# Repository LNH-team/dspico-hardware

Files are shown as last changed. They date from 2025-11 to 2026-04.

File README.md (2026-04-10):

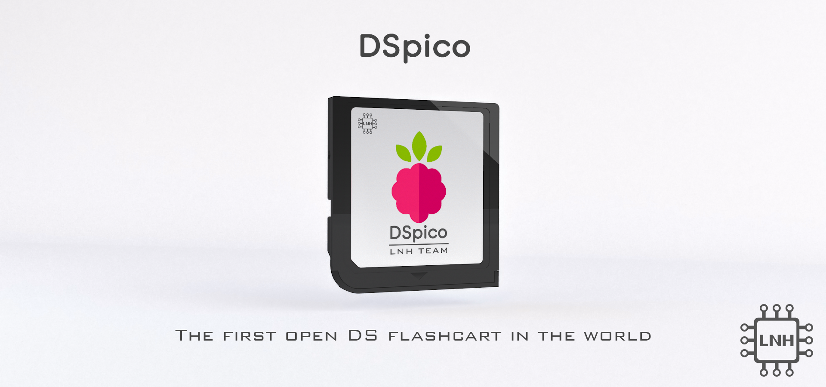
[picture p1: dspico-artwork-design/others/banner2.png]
DSpico-banner


# DSpico Hardware
## 🗺️ Contents
- [ℹ Introduction](#ℹ-introduction)
- [❔ About this repository](#-about-this-repository).
- [🎮 DSpico PCB](#-dspico-pcb)
- [🧰 DSpico Shell](#-dspico-shell)
- [🎨 Artwork: Stickers and box art](#-artwork-stickers-and-box-art)
- [📦 Instructions](#-instructions)
- [🛠 Development](#-development)
- [👥 Contributions](#-contributions)
- [👾 Discord](#-discord)
- [📋 LNH Team Statement](#-lnh-team-statement)
- [⚖ License](#-license)

## ℹ Introduction
### What is DSpico?
DSpico is the world's first open-source DS(i) flashcart, created by the LNH team. Everything from the PCB, shell, stickers, and box art is open-source. You can either build it yourself as a DIY project or have it made by a manufacturer.

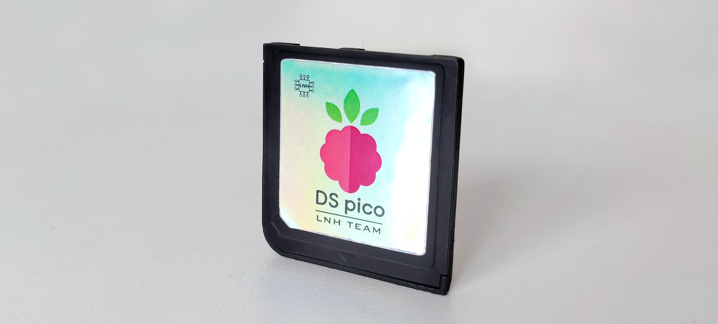
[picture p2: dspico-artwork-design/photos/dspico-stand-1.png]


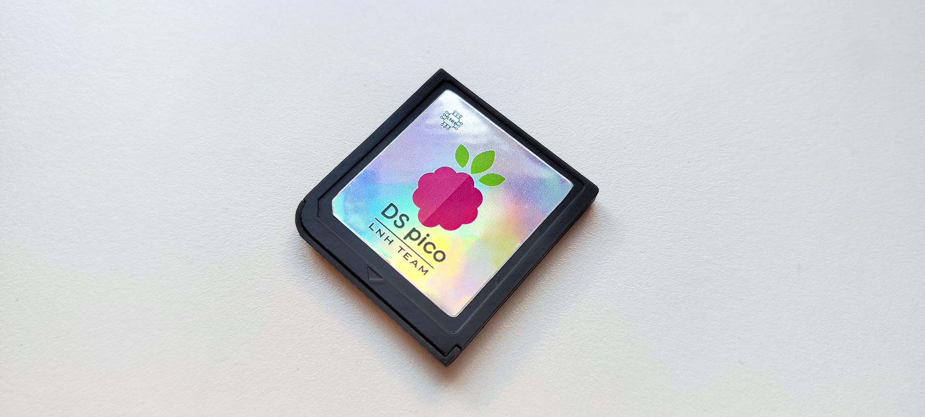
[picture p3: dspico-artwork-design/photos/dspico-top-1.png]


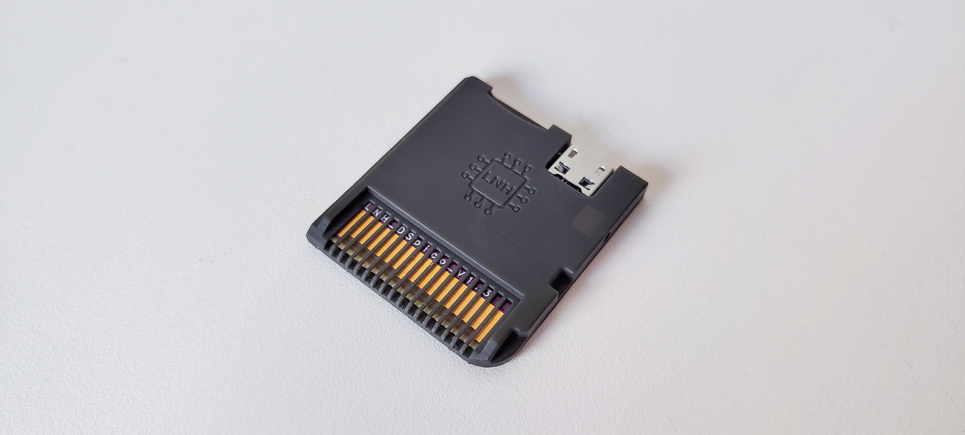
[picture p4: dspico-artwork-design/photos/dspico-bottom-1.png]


### Features
- RP2040 microcontroller
- 16 Mbit flash memory
- Micro USB port
- Micro SD slot
- Development port
- Two LEDs (red and blue)
- Dual power support: can be powered by USB and DS simultaneously (by ORing circuit)

With the [DSpico Firmware](https://github.com/LNH-team/dspico-firmware):
- Sequential SD read speed: up to 6MB/s
- Power consuption: ~57 mW
- Compatible with DSi mode
- Compatible with [Pico Loader](https://github.com/LNH-team/pico-loader) and [Pico Launcher](https://github.com/LNH-team/pico-launcher)

## ❔ About this repository
This repository contains the necessary files for the hardware of the DSpico, including a PCB, CAD design of the shell, stickers for cartridge and box art.

## 🎮 DSpico PCB
The PCB design is located in the [`dspico-pcb`](dspico-pcb) folder. This folder contains all the necessary files for PCB fabrication, as well as the design files created using the electronic design software.

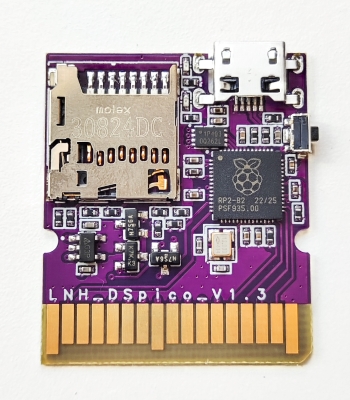
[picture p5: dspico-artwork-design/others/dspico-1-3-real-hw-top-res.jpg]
DSpico-top

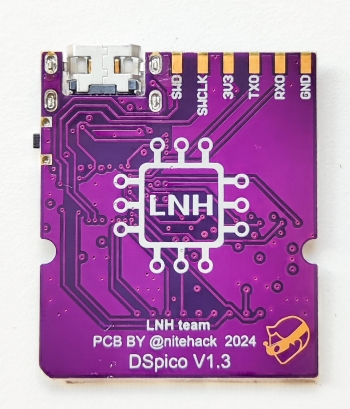
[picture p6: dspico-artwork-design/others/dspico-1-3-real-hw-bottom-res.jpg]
DSpico-bottom

### 📂 Included Subfolders:
- [`design-files`](dspico-pcb/design-files): PCB schematic and layout of DSpico. (KiCad format)
- [`fabrication-files`](dspico-pcb/fabrication-files): Gerber files, Pick&Place files and BOM for PCB fabrication of DSpico.
- [`docs`](dspico-pcb/docs): Documentation for manufacturing and assembling DSpico.

### 🔌 Pinout

| **Peripheral**  | **Pin name - Peripheral** | **Pin name - RP2040** | **Pin number - RP2040** |
|---|---|---|---|
| **DS Slot** | D0 | GPIO12 | 15 |
| | D1 | GPIO13 | 16 |
| | D2 | GPIO14 | 17 |
| | D3 | GPIO15 | 18 |
| | D4 | GPIO16 | 27 |
| | D5 | GPIO17 | 28 |
| | D6 | GPIO18 | 29 |
| | D7 | GPIO19 | 30 |
| | CLK_DS | GPIO11 | 14 |
| | ROM_CS | GPIO10 | 13 |
| | SPI_CS | GPIO21 | 32 |
| | IRQ | GPIO20 | 31 |
| | RST_DS | GPIO09 | 12 |
| **SD slot**| CLK_SD | GPIO03 | 5 |
| | DAT0 | GPIO05 | 7 |
| | DAT1 | GPIO06 | 8 |
| | DAT2 | GPIO07 | 9 |
| | DAT3 | GPIO08 | 11 |
| | CMD | GPIO04 | 6 |
| **DEV port**| SWD | SWD | 25 |
| | SWCLK | SWCLK | 24 |
| | TX | GPIO0 | 2 |
| | RX | GPIO1 | 3 |
| **Blue LED** | LED_B | GPIO28 | 40 |
| **Red LED** | LED_R | GPIO27 | 39 |

## 🧰 DSpico Shell

The CAD design of the shell is located in the [`dspico-shell`](dspico-shell) folder. This folder contains 3D models of the shell (output 3d models and design files), which can be viewed and modified using CAD design software Autodesk Inventor

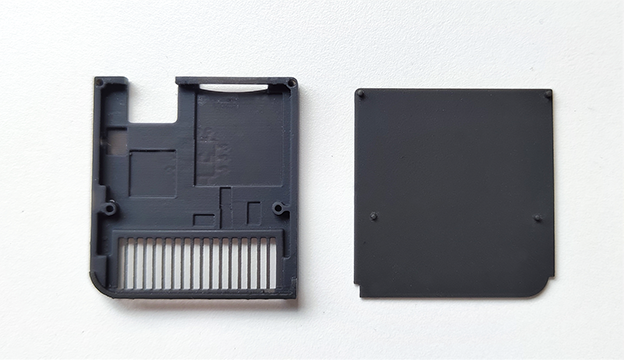
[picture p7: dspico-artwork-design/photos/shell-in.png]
DSpico-shell-in

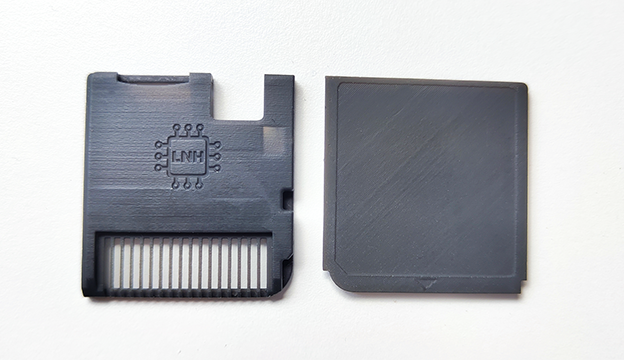
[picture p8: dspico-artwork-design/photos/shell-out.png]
DSpico-shell-out

### 📂 Included Subfolders:
- [`design-files`](dspico-shell/design-files): Contains source design files for the shell
- [`3d-models`](dspico-shell/3d-models): Contains 3D models of the shell in STL and STEP format for fabrication.

## 🎨 Artwork: Stickers and box art
The stickers and box art design are located in the [`dspico-artwork-design`](dspico-artwork-design).  This folder contains stickers for cartridge and box art in SVG, PSD and PNG formats.

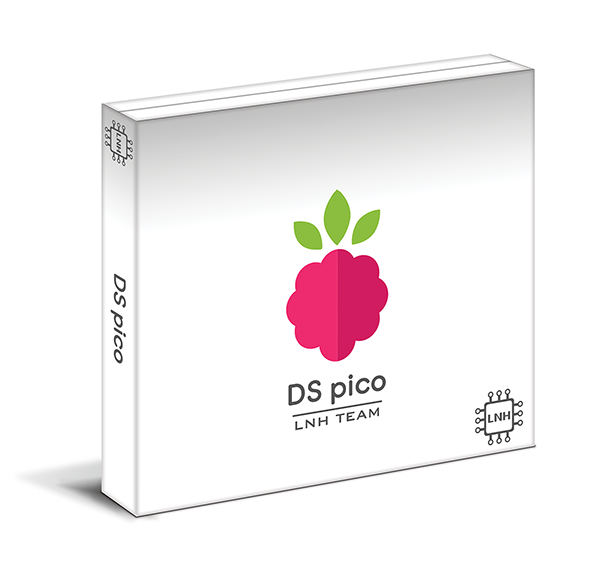
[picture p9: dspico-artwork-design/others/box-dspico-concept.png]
DSpico-box

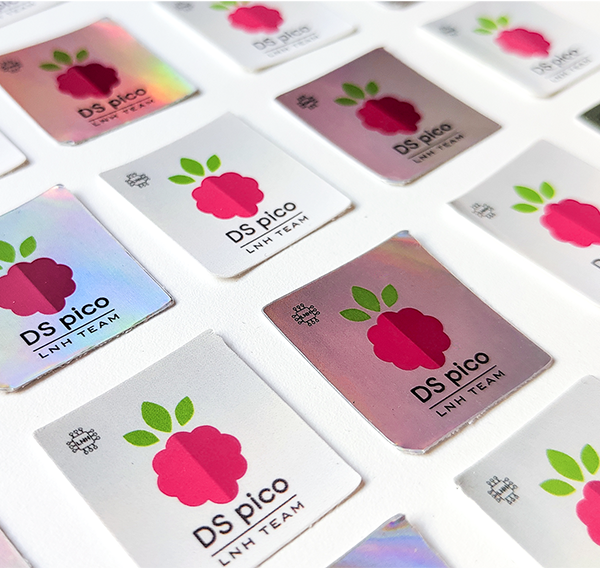
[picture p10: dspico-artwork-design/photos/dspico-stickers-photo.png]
DSpico-stickers


### 📂 Included Subfolders:
- [`stickers`](dspico-artwork-design/stickers): Stickers to print and put on your DSpico cartridge.
- [`box-art`](dspico-artwork-design/box-art): Box art design to print and put on your DS box.
- [`logo`](dspico-artwork-design/logo): DSpico logo in different formats.
- [`others`](dspico-artwork-design/others): Other graphics related to DSpico

## 📦 Instructions
### 1️⃣ Build
1. **Manufacture the PCB and Shell**<br>
    Start by producing both the PCB and the shell. Go to the respective sections, [`dspico-pcb`](dspico-pcb) and [`dspico-shell`](dspico-shell), and read the README file in each to understand how to create these parts.

2. **Optional: Customize with a Sticker and Box Art**<br>
    If desired, you can print a sticker from the stickers section and add box art [`dspico-artwork-design`](dspico-artwork-design) for storing your DSpico (for example, by reusing an existing box).

### 2️⃣ Assembly
Once you have both the PCB and the shell manufactured, the next step is to assemble them. Follow these steps:
1. First, insert the PCB into the bottom part of the shell.
2. Next, attach the top part of the shell by aligning the pegs with the holes in the bottom part.
3. Stick your favorite DSpico sticker on top part.
Make sure everything fits, and your DSpico will be ready for the next steps!

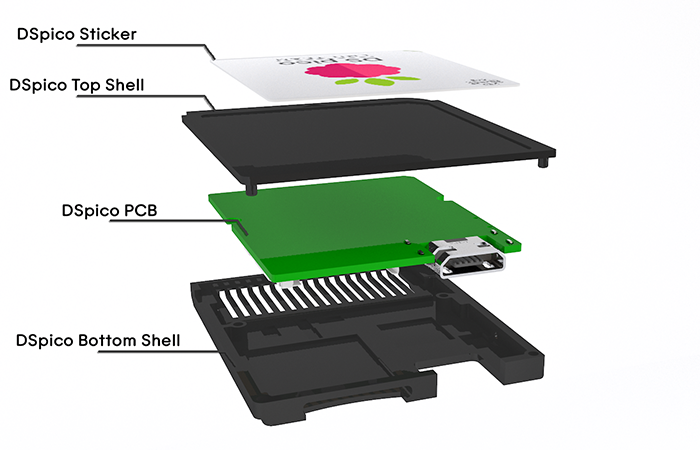
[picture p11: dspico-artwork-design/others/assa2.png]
DSpico-assembly2

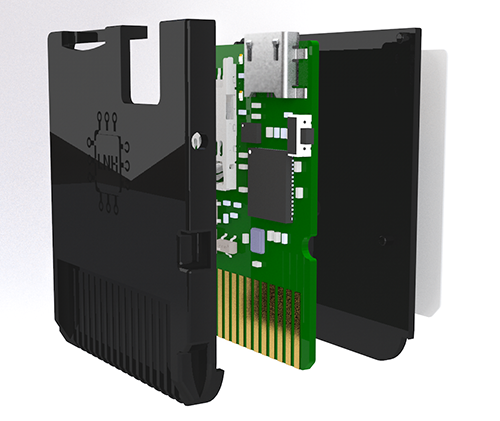
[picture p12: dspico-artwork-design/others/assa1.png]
DSpico-assembly1


### 3️⃣ Setup the software
Follow the [guide](https://github.com/LNH-team/dspico/blob/develop/GUIDE.md) for instructions on how to compile and setup the firmware and the contents of the micro SD card.

## 🛠 Development
The DSpico features a development port for creating new applications and developing new peripherals. The available communication ports are as follows:
- UART
- I2C
- x2 GPIO
- SWD (debug)

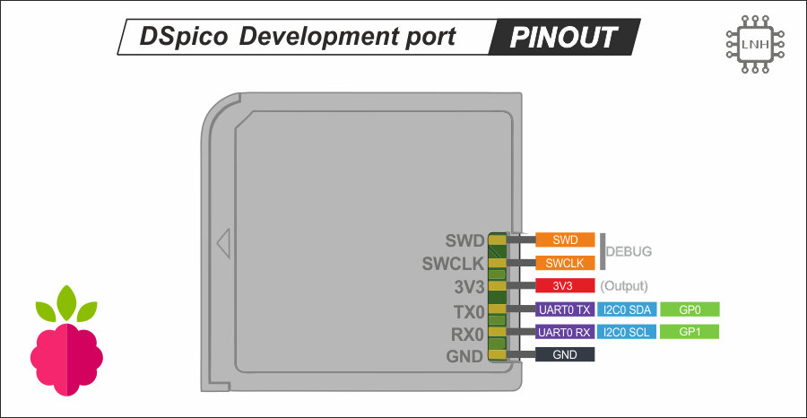
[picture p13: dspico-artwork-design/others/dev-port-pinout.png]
development port


As for the power it can provide to peripherals, it is:
- 3.3 V (up to 50 mA)

The pitch between pins of this port is 2.54 mm such that some connectors can be soldered (as long as it does not interfere with the rest of the DSpico mechanics). For example a male or female header.

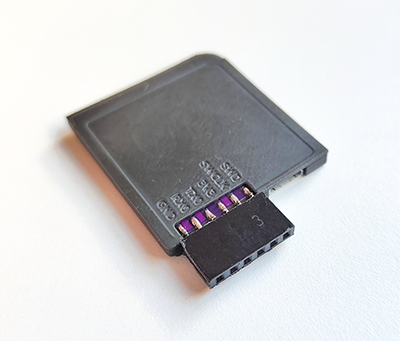
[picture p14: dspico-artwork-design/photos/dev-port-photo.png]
DSpico-dev-port

## 👥 Contributions

Contributions are welcome. If you wish to improve the PCB or shell designs, feel free to submit a pull request!

### Contributors:

#### PCB:
 - [nitehack](https://www.github.com/nitehack)
 - [Gericom](https://github.com/Gericom) (first DSpico prototype)

#### Shell:
 - rcuevas
 - [nitehack](https://www.github.com/nitehack)

#### Artworks:
 - [nitehack](https://www.github.com/nitehack)

## 👾 Discord
- [DS⁽ⁱ⁾ Mode Hacking!](https://discord.gg/fCzqcWteC4)

## 📋 LNH Team Statement
We wish to make it clear that the LNH team has no affiliation with any commercial projects, and we do not endorse or engage in any for-profit endeavors concerning DSpico or related materials. This statement serves as a formal disavowal of any financial or business dealings that may arise in relation to DSpico, and we take no responsibility for any actions or transactions carried out by third parties in this regard.

## ⚖ License

This project is licensed under the CC BY-SA 4.0 License. See the [`LICENSE`](LICENSE) file for more details.

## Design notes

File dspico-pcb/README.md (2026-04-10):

# DSpico PCB

This repository contains the files and configurations needed to fabricate and assemble the PCB for the **DSpico** flashcart. You can manufacture with the manufacturer you prefer. In this readme we include a guide on how to order it from [JLCPCB](https://cart.jlcpcb.com/quote?spm=Jlcpcb.Homepage.1006)

## 📂 Included Subfolders:
- [`design-files`](./design-files): PCB schematic and layout of DSpico. (KiCad format)
- [`fabrication-files`](./fabrication-files): Gerber files, Pick&Place files and BOM for PCB fabrication of DSpico.
   - 📂 `Gerber`: Gerber files required for fabrication.
   - 📂 `NC Drill`: Contains the NC Drill files required for PCB hole drilling.
   - 📂 `BOM`: Bill of Materials (BOM) for assembly.
   - 📂 `Pick Place`: Pick and Place files for component placement.
- [`docs`](./docs): Documentation for manufacturing and assembling DSpico. (including schematics)

---

## 📦 Guide to get a PCB
DSpico-top
DSpico-bottom

### 1. PCB Order- JLCPCB
> [!WARNING]
> This guide was last reviewed on **November 22, 2025**. 
> Please be aware that the manufacturer's website and production processes may have changed since this date. 

1. **Prepare files**
   - Make a compressed file ZIP of `NC Drill` and `Gerber` folder with the name of `Gerber.zip` (for example)
2. **Go to the Website of manufacturer**
  
   - Visit [JLCPCB PCB Quote](https://cart.jlcpcb.com/quote).

3. **Upload Gerber and NC Drill Files**:

   - Upload the `Gerber.zip` file to the JLCPCB configurator.

4. **PCB Configuration**

   - Base Material: **FR-4**
   - Number of Layers: **4 layers** (auto-detected after uploading Gerber files).
   - Dimensions: (auto-detected after uploading Gerber files).
   - Quantity: **5 units** (minimum)

>PCB Specifications
   - Deburring/Edge rounding: Yes
   - Different Design: 1
   - Delivery Format : Single PCB
   - PCB Thickness: **0.8mm** (very important)
   - PCB Color: (As you want but normally green is the cheapest)
   - Silkscreen: **White** 
   - Material Type: FR4 TG135
   - Surface Finish: **ENIG**
   - Gold Thickness: **1U"**. (Or more, but more expensive)
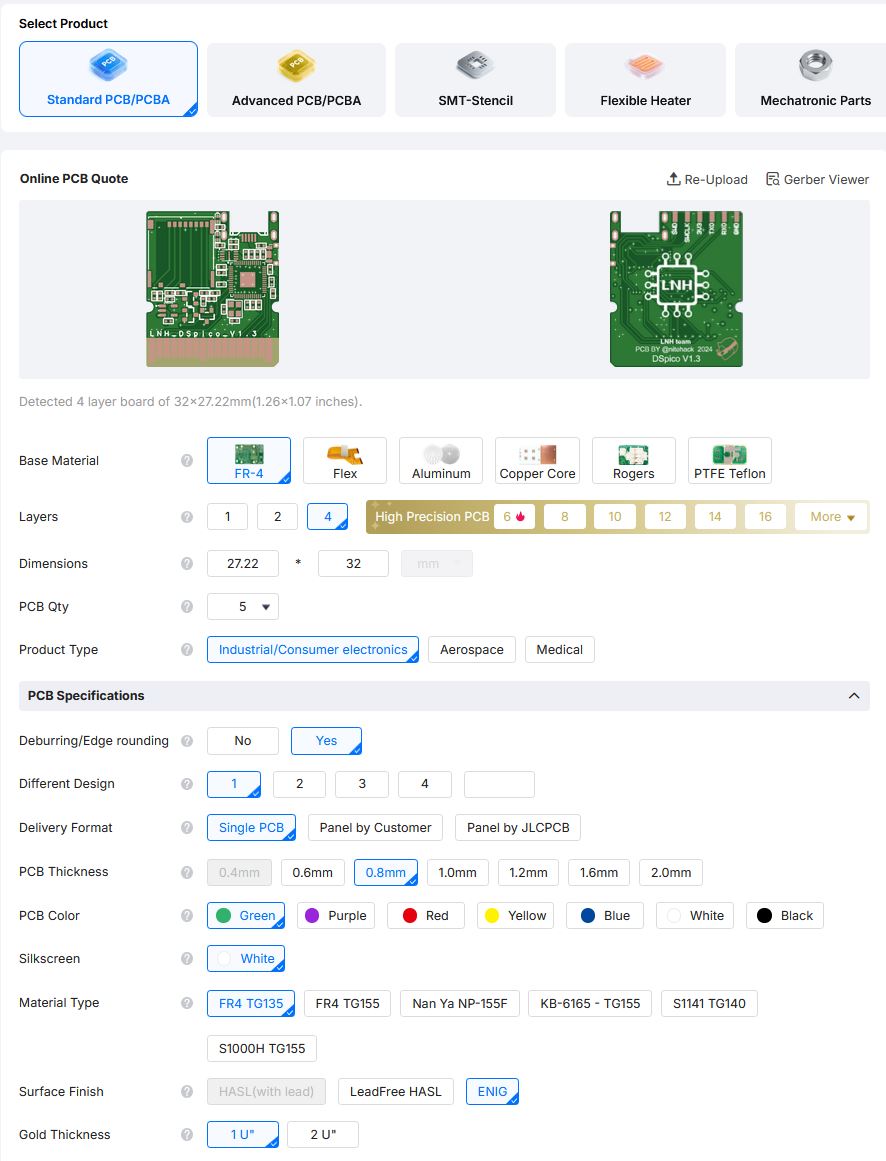
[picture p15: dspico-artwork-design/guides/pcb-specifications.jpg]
pcb-specifications


>High-spec Options
   - Outer Copper Weight: **1 oz**
   - Inner Copper weight: **0.5 oz**
   - Specify Layer Sequence: YES
      
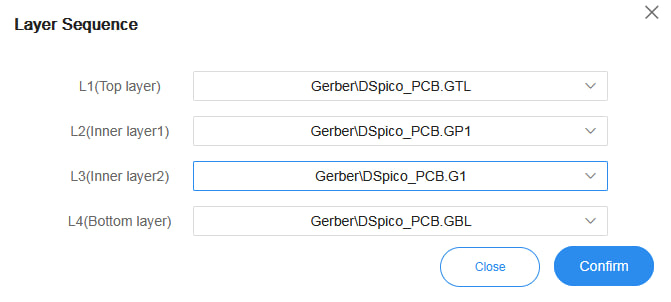
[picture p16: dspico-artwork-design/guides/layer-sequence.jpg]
layer-sequence


   - Specify Stackup: **No**
   - Via Covering: **Plugged**
   - Min via hole size/diameter: **0.3mm (0.4/0.45mm)**
   - Board Outline Tolerance: **±0.2mm (Regular)**
   - Confirm Production File: **Yes**
   - Mark on PCB: **Remove Mark**
   - Electrical Test: **Flying Probe Fully Test**
   - Gold Fingers: **No**
   - Castellated Holes: **No**
   - Press-Fit Holes: **No**
   - Edge Plating: **No**
   - Blind Slots: **No**
   - UL Marking: **No**
   - Via Plating Method: **Not Specified** 
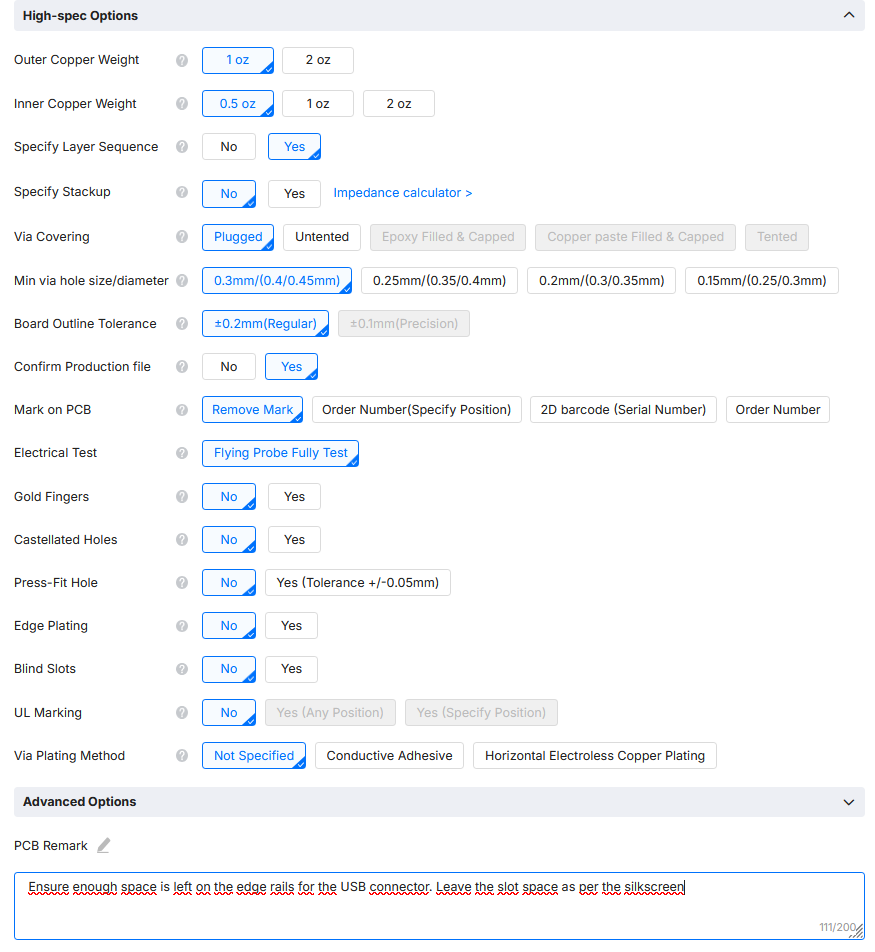
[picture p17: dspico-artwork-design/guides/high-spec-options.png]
high-spec-options

>PCB Remark
>
Add the next note:

**Ensure enough space is left on the edge rails for the USB connector. Leave the slot space as per the silkscreen**

If they contact you via email after placing the order about this note, attach the following image

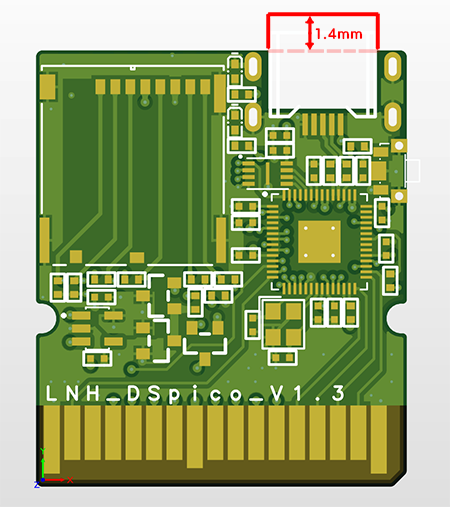
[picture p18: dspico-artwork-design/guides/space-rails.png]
space-rails


---

### 2. PCB Assembly Order- first step - JLCPCB

1. **Assembly Type**:
   - **Assemble top side**.
   - PCBA Type: **Standard**
   - Assembly Side: **Top side**
   - PCBA Qty: **5**. (Or custom Qty)
   - Edge Rails/Fiducials: **Added by JLCPCB**
   - Confirm Parts Placement: **Yes**
   - Stencil Storage: **No**
   - Fixture Storage: **No**
   - Parts Selection: **By Customer**

2. **Advanced Options**:
   - Bake Components: **No**
   - Board Cleaning: **Yes**
   - Packaging: **Antistatic bubble film**.
   - Solder Paste: **SN96.5%, Ag3.0%, Cu0.5%(260ºC)**
   - Add paste for unpopulated pad & step stencil opening: **No**
   - Function test: **No** 
   - Photo confirmation: **No**
   - Conformal Coating (cleaning included): **No**
   - Depanel boards & edge rail before delivery: **No**
   - Flying Probe Test: **No**
   - Nitrogen reflow soldering: **No**
   - PCBA remark: **No**

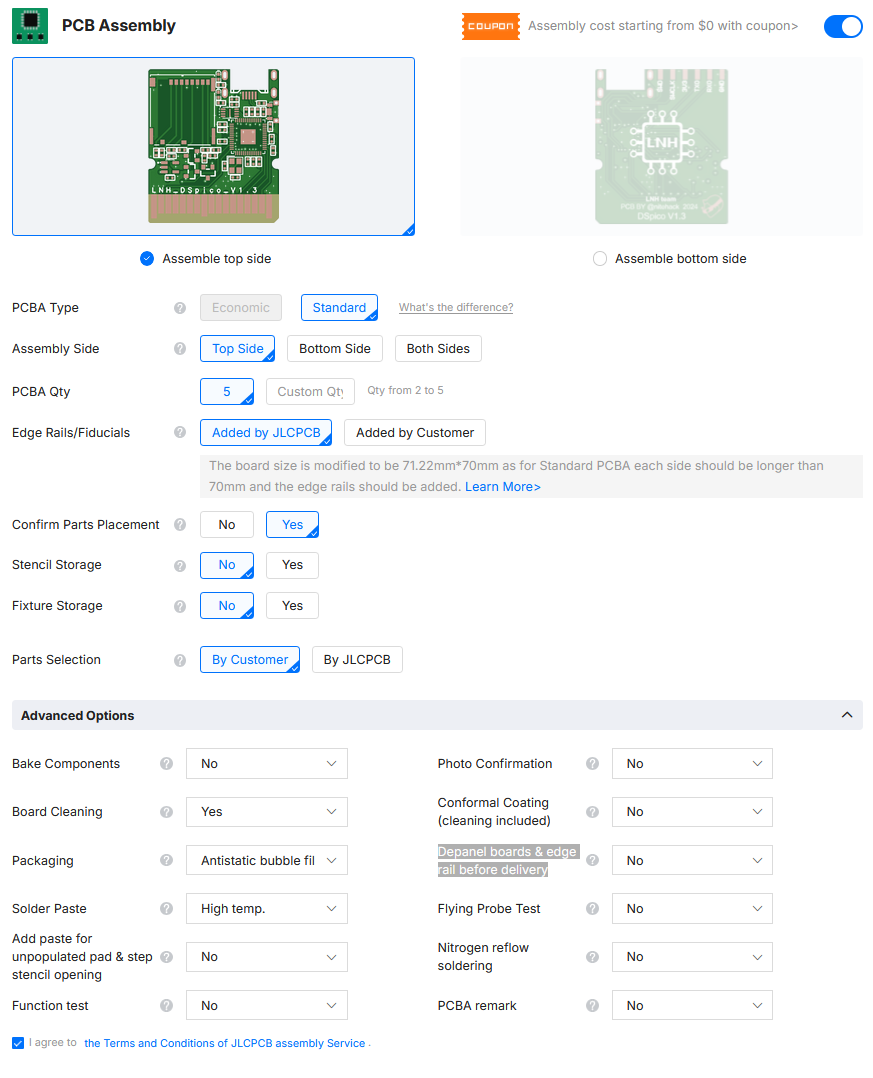
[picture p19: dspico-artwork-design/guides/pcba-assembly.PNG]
pcba-assembly


3. On the **Price Summary** window, click **Next**.

---

### 3. PCB Assembly Order - second step - JLCPCB

Follow these steps to continue with the process

### Preview pcb specifications
On the **Preview PCB** page, click **Next** to proceed.  

### Add Required Files for assembly 
In the next window, upload the necessary files for your DSpico PCB:  

   1. **Add BOM File**  
      - Click on **Add BOM File**.  
      - Search for and select the Bill of Materials (BOM) file:  
        - `"Bill of Materials-DSpico.xlsx"` (Ensure it matches the version of DSpico you are building).  

   2. **Add Pick-and-Place (CPL) File**  
      - Click on **Add CPL File**.  
      - Search for and select the Pick and Place file:  
        - `"Pick Place for DSpico_PCB.csv"` (Ensure it matches the version of DSpico you are building).  

   3. Once both files are uploaded, press **Process BOM & CPL**.  
   
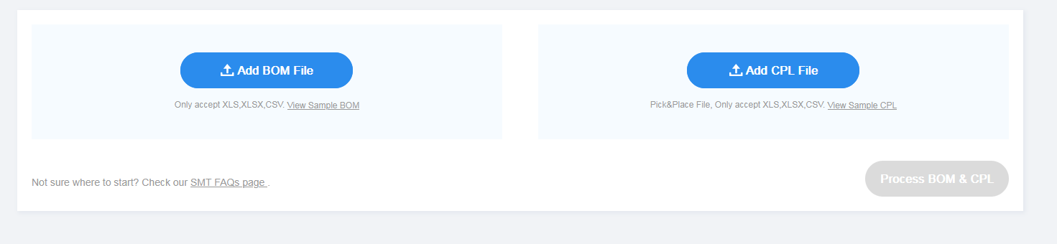
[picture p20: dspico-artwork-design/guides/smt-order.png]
SMT Order Example
   

### Verify Components  
In the next window, carefully verify the components:  

1. Check that each component selected by the **JLCPCB tool** matches the corresponding part in the BOM:  
   - Use the file `"Bill of Materials-DSpico.xlsx"` for reference.  
   - Ensure the selected part is the same or a suitable alternative.  
     
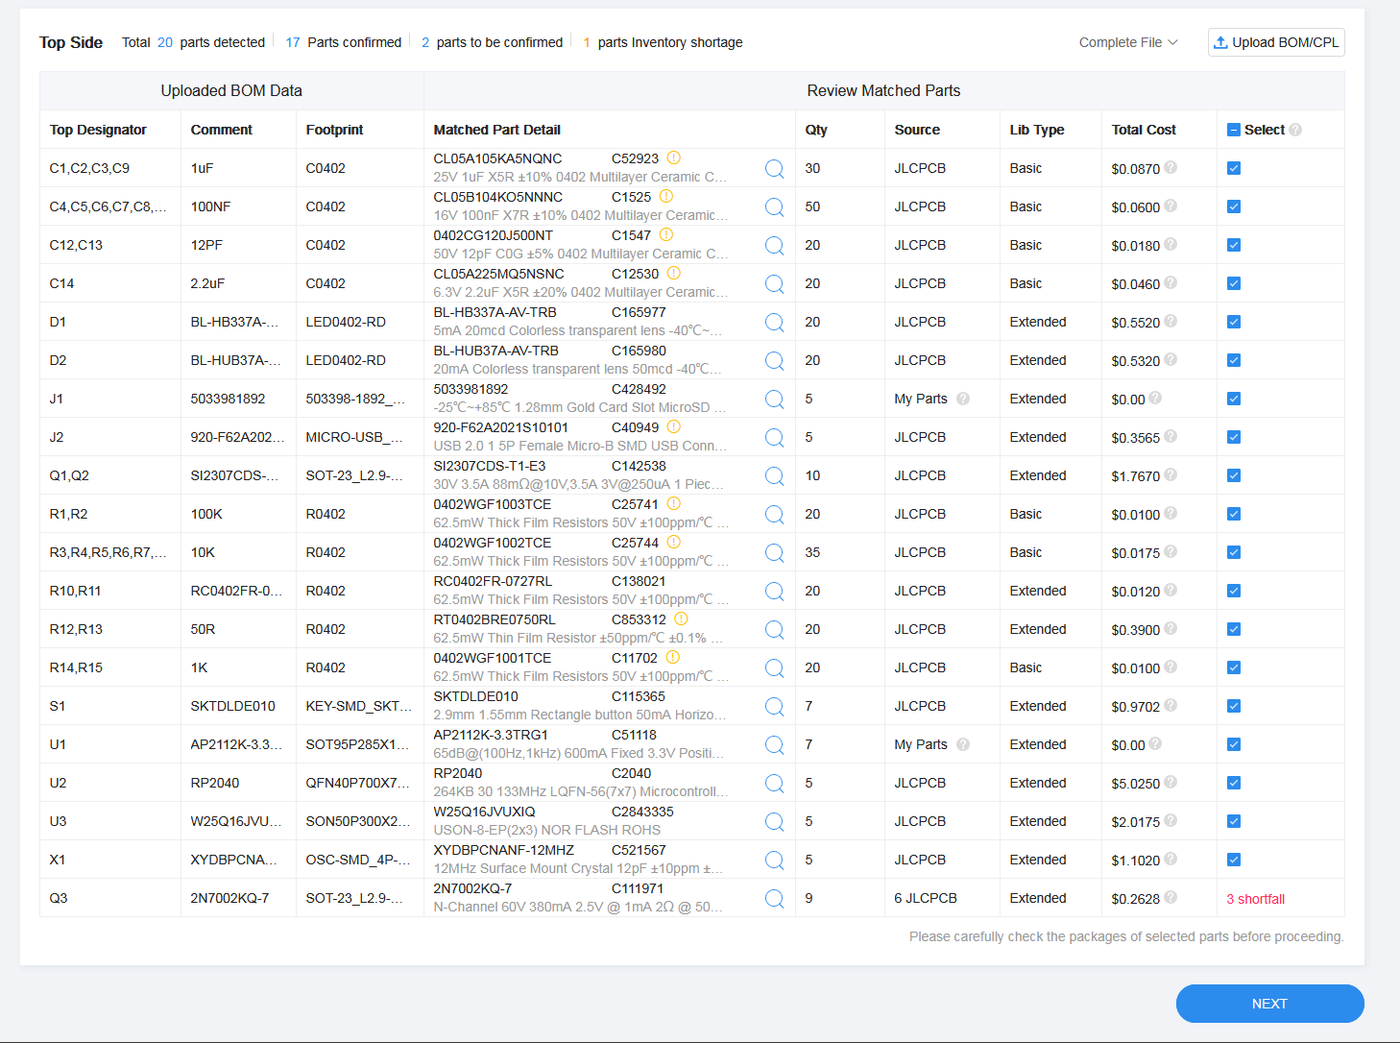
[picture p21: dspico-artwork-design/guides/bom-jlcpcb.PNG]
Component Verification Example
     
     
     (The image is just a reference, please follow the components indicated in the BOM file)

> [!IMPORTANT]
> If the components do not match, there is a risk of malfunction or improper operation of the DSpico. **Double-check every part detail carefully. It's your responsibility**  

> [!TIP]  
 > JLCPCB may sometimes show certain parts as out of stock. However, other users may have that part in their accounts, which you can purchase and add to your order. If this is not an option, you can place an order for the part separately, though you’ll need to wait for JLCPCB to buy them and receive them.  After using the necessary components, you can sell your parts on your account. More info: https://jlcpcb.com/help/article/What-is-JLCPCB-Parts-Pre-order-Service
 > You can also look for an alternative to the component by clicking the magnifying-glass icon next to it and searching for a compatible replacement.

### Check Component Placement  
1. In the next window, verify the component placement:  
   - Ensure the **position**, **rotation**, and **Pin 1 orientation** are correct.  
     
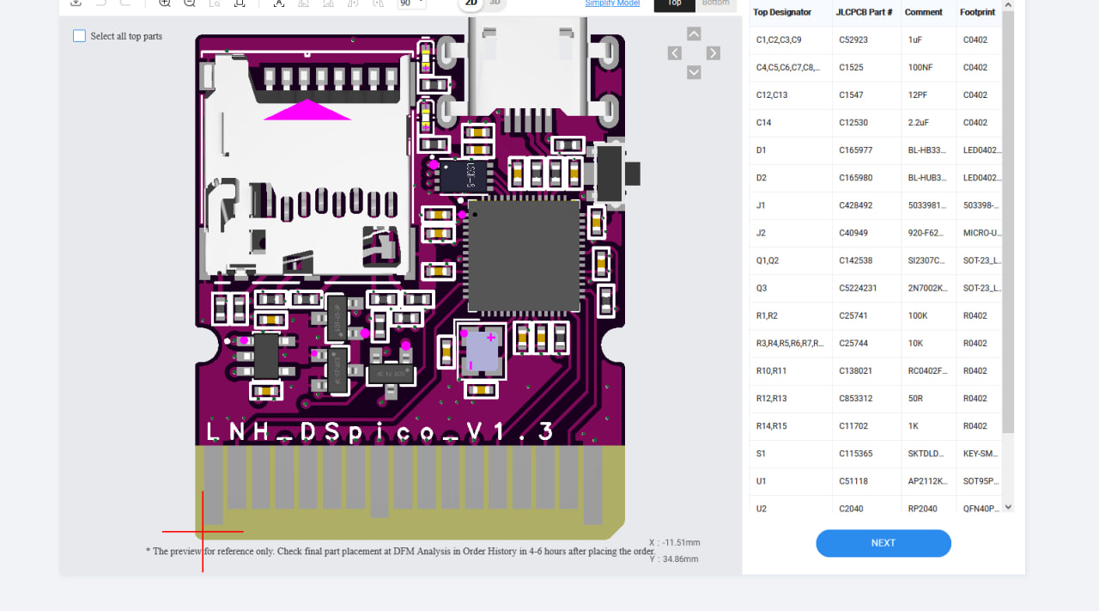
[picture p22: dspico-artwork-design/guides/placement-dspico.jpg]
Placement Verification Example
     

### 3. Finalize the Process  
1. Click **Next** to proceed through the final steps of the process.  
2. Wait for JLCPCB to review your order.  
3. Review and accept their feedback before making the payment.  

--- 

## 💡 Recommendations
- We recommend using a **Hard Gold** surface finish if you can afford it. This is not possible with JLCPCB, but it is available with PCBWAY and other manufacturers. It will significantly improve the conductivity of the PCB pins, reducing detection issues with the DSpico.

## ❓ FAQ
>- Can I order just 1 PCB assembled?

Depending on the manufacturer, you may or may not be able to do this, but it will be very expensive. They usually ask for a minimum of 2 assembled PCBs. We recommend ordering 5 assembled PCBs.

>- What happens if a component of JLCPCB is out of stock? 

You must find an alternative or purchase that component from the JLCPCB library. See here for more information: https://jlcpcb.com/help/article/What-is-JLCPCB-Parts-Pre-order-Service

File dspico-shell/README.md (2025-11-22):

# DSpico shell
## ℹ Introduction
To obtain a shell, you can print it yourself if you have an SLA printer, or you can order it online from manufacturers like PCBWAY and JLCPCB. If you order the shell from one of the mentioned services, please follow the guide in this readme.

## 📂 Included Subfolders:
- [`design-files`](design-files): Contains source design files for the shell
    - 📄 `dspico-shell.ipt`: Inventor design file of DSpico shell  
- [`3d-models`](3d-models): Contains 3D models of the shell in STL and STEP format for fabrication.
    - 📄 `dspico-shell-top_vX-Y.stl`: Printing file for the top part of the shell.
    - 📄 `dspico-shell-bottom_vX-Y.stl`: Printing file for the bottom part of the shell.
    - 📄 `dspico-shell-top_vX-Y-FR.stl`: Printing file for the top part of the shell, with forced rotation (-FR), (Please use this file when sending it to the manufacturer for the shell).
    - 📄 `dspico-shell-bottom_vX-Y-FR.stl`: Printing file for the bottom part of the shell, with forced rotation (-FR), (Please use this file when sending it to the manufacturer for the shell).
---
## 📦 Guide to get a shell

DSpico-shell-in

> [!WARNING]
> Please do not skip any steps otherwise the shell could go wrong.

> [!CAUTION]
> **Request both the shell's top part and bottom part in the same order with the same material** .
>
> Ordering them separately or in different materials may result in mismatched parts. This is because the manufacturer might produce them on different printers with varying tolerances, and tolerances can also differ between materials.

### JLC3DP (JLCPCB)
1. **Go to the Website of manufacturer**

    Visit [JLCPCB 3D Printing Quote](https://jlc3dp.com/3d-printing-quote).

2. **Upload shell parts**

    Upload [`dspico-shell-bottom_vX-Y-FR.stl`](3d-models/v1.4/forced-rotation-printing/dspico-shell-bottom_v1-4-FR.stl) and [`dspico-shell-top_vX-Y-FR.stl`](3d-models/v1.4/forced-rotation-printing/dspico-shell-top_v1-4-FR.stl) STL file. Wait for the system to analyze it.

4. **Select Printing Options:**

(Select the same options for both the top and bottom 3d parts)
- 3D Technology: `SLA (Resin)`.
- Material: `Black Resin` (recommended to avoid issues).
- Surface Finish: `Yes`. `Sanding``
- Qty: (number of pieces you want)
- Product Desc: `Toys Part -HS Code 9`
- 3D Remark (Very IMPORTANT):

Add the next note:
> IMPORTANT:
>
> -I take breakage risks.
>
> -DO NOT ROTATE THE 3D FILE IN ANY OF ITS AXES WHEN YOU GO TO PRINT JUST ADD SUPPORTS
>
> -Send me an email to verify

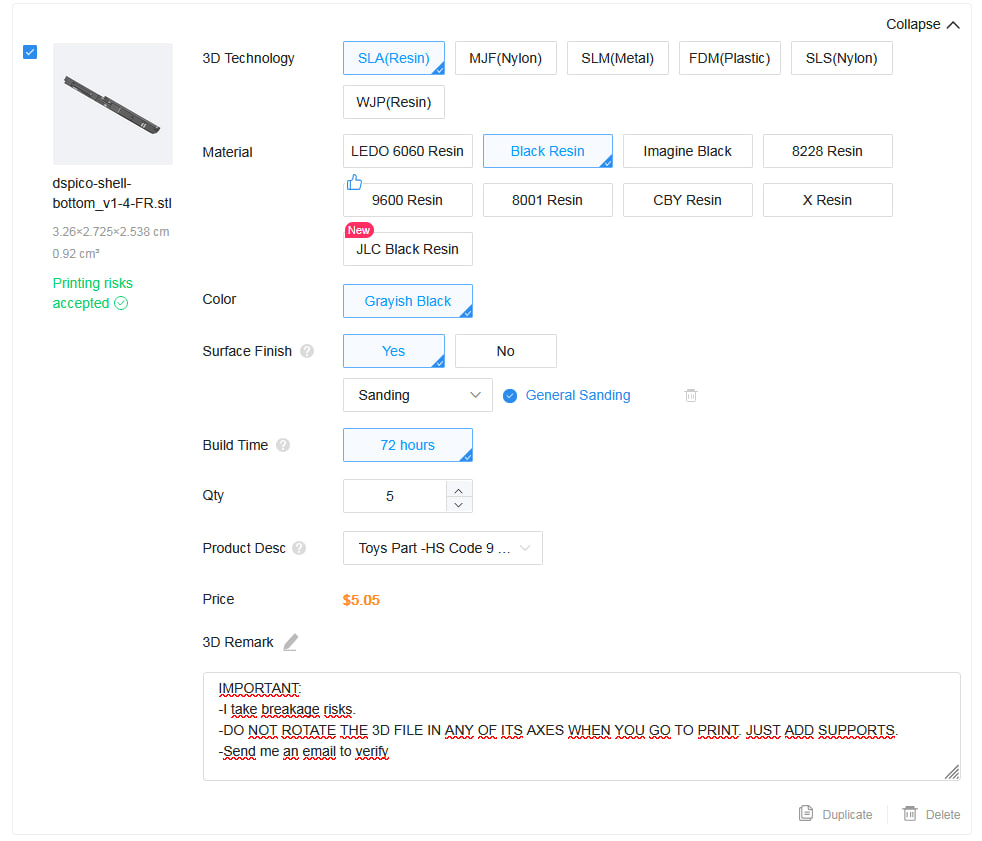
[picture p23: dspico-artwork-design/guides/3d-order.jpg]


5. **Accept Risks**

    System will warn about thin walls, select `Yes, I will take the risks.`
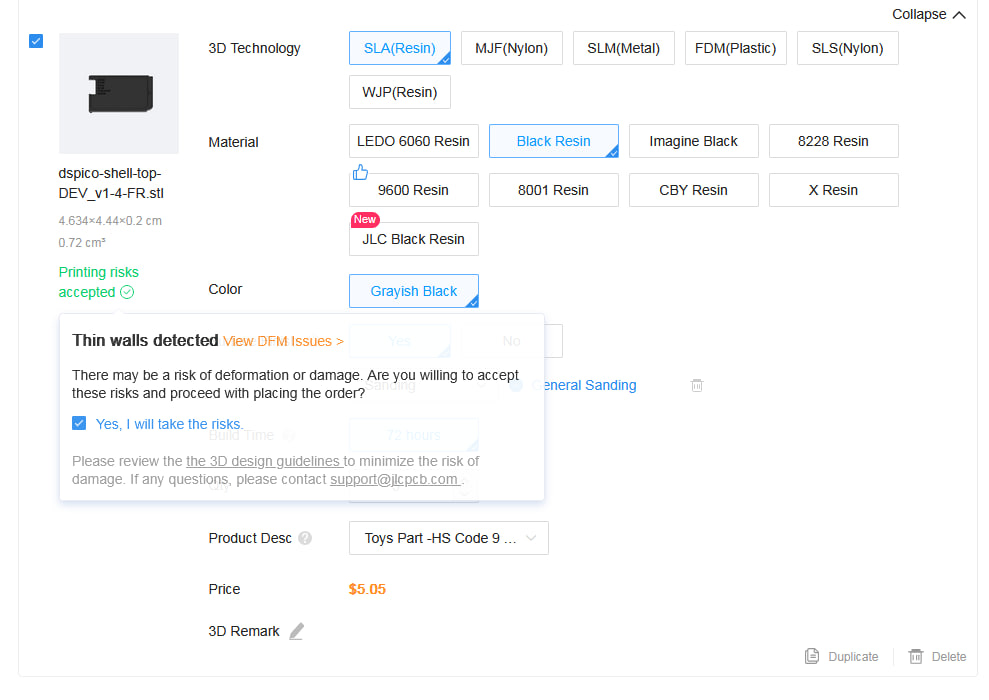
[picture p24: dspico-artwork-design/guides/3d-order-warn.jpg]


8. **Review and Place Order**

    Double-check all settings and confirm your order.
   
10. 📧 **Email conformation of JLCPCB and send an answer**

    After placing your order, you will need to wait for an email from JLCPCB. (normally less than 24h)

    In this email, they will usually remind you about the risks of breakage due to the thin walls and they will ask for an image of the orientation of the parts.

    When you receive the email, reply with the following message and attach the images shown below:

> Hello,
>
> As I said in the notes, I accept the risks of deformation, breakage, etc.
>
> And as for the placement, put it as it appears in the file as of 3D file, do not rotate them when you do the placement for printing, please I attached images of 2 files:
>
> - dspico-shell-bottom:
> 
> (45º)
>
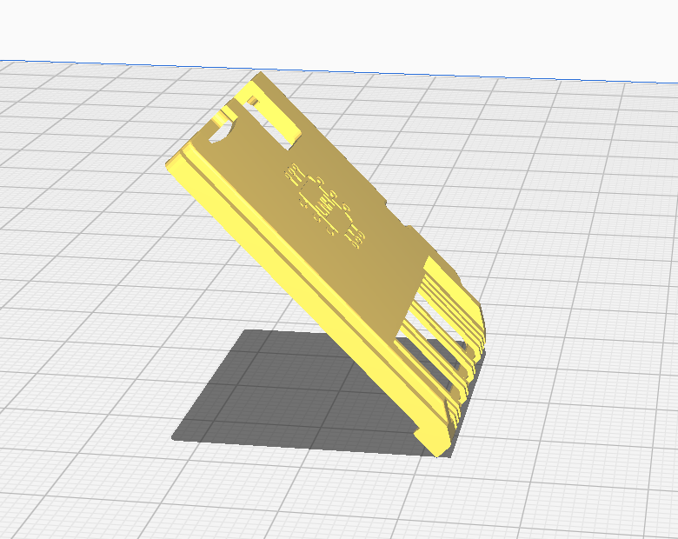
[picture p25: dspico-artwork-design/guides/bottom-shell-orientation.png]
> 
>
> - dspico-shell-top:
>
> (90º)
>
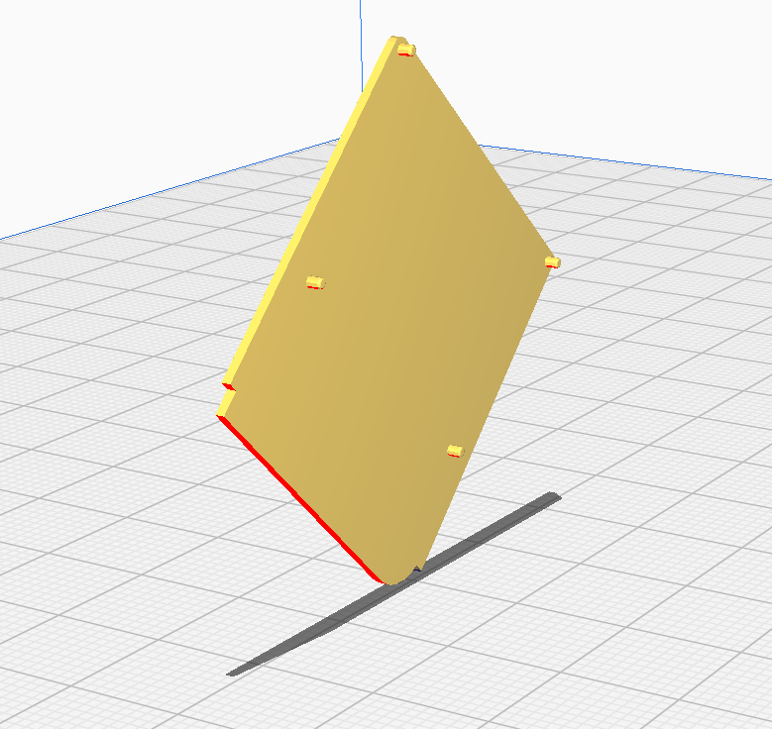
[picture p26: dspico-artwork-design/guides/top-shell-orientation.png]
> 

> [!WARNING]
> Don't forget to attach the images to the email

11. **Payment**

    After sending the email, you will need to wait for the 3D parts to be approved by the manufacturer. Once approved, you will need to make the payment.

13. **After receive the order**

    It is important that when you receive your shell order, you perform a visual inspection 🕵️‍♂️ and pay special attention to the rails on the bottom part to ensure there is no leftover plastic (due to the supports included in the printing process). If there is any, carefully remove it with a cutter.

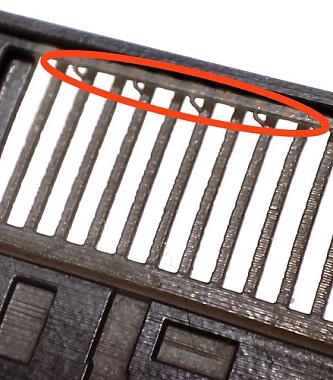
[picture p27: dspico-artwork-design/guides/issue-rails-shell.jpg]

    
---
## ⚠ Warnings
Please note that sometimes manufacturers may not follow the process correctly even when provided with instructions. Additionally, due to the tolerances of 3D printing technology, there may be slight variations in dimensions. It is recommended to use SLA technology, as it offers the smallest tolerance (+-0.2mm) and is provided by PCBWAY and JLCPCB manufacturers.

If the appropriate material is not chosen, the results can be poor. Don't go by appearance. For example, the transparent resin from JLCPCB and PCBWAY would be the worst decision you could make since the dimensions change after curing and the piece deforms easily.

So please select one of the materials recommended in the next section

## 💡 Recommendations

### Materials
 - [Comparison of 3D resin materials](https://docs.google.com/spreadsheets/d/1kmLcHB08pd6XpYTxQfuauXQA3aGOPxwUc3_S_YKbFcI/edit#gid=265174143) 

For the best results in your 3D prints, it is recommended to use one of the materials of the following list:
#### JLCPCB
- Black resin
#### PCBWAY
-  UTR Therm

### Orientation
Orientation in 3D printing is very important. 

If you do not tell the manufacturer the orientation of how to print the shell, the probability that the shell will come out wrong is high. We highly recommend that you use the stl file that is in the `forced-rotation-printing` subfolder and tell the manufacturer not to rotate the part in any axis when you go to print the part and additionally send an email sending a screenshot of the orientation that wants.

You don't know the headaches this has brought.

## ❓ FAQ
>- Can I print the shell with my FDM printer? (printer of filament)

You can print it, but the precision is not as good compared to a SLA printer. You risk it not fitting properly, and the rails are difficult to print. Most importantly, these shell rails can damage the inner pins of your DS's slot if they are not printed well and with the right precision. So, for the sake of your DS, avoid it.

>- Why I have to send a email to manufacturer about specific orientation in 3d files?

The shell has thin walls for manufacturing by most producers, but it is possible to print it without issues using a specific orientation.

Manufacturers do not thoroughly analyze the  3d parts; they simply rotate it 45º on any axis and print it as is. This often leads to deformations and breakages.

Therefore, it is very important to send the email to minimize these problems as much as possible.

>- Can I use a different material instead of the recommended one? (e.g., transparent or another color)

We recommend using the materials suggested in this guide. Otherwise, you may encounter issues such as incorrect dimensions, deformations, or parts that are too flexible.

If you have tested a different material with good results, please let us know!

Check the next spreadsheet to avoid wasting your time and money: [Comparison of 3D resin materials](https://docs.google.com/spreadsheets/d/1kmLcHB08pd6XpYTxQfuauXQA3aGOPxwUc3_S_YKbFcI/edit#gid=265174143) 

## 🛠️ Issues
 - [Findings in the DSpico shell 3D printing process with resin](https://docs.google.com/document/d/161Bof1LAfQEwKCZYXi1A_FSsFC0sCSEptYKGwLPbTv0/)
 - [Comparison of 3D resin materials](https://docs.google.com/spreadsheets/d/1kmLcHB08pd6XpYTxQfuauXQA3aGOPxwUc3_S_YKbFcI/edit#gid=265174143)

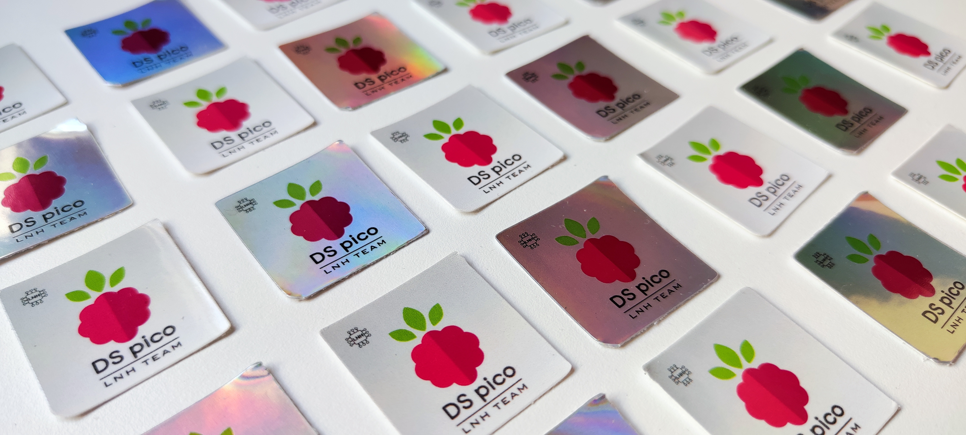
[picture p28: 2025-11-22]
dspico-artwork-design/photos/stickers.jpg

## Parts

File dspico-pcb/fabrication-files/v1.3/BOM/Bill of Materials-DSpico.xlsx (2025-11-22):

Comment | Description | Designator | Footprint | LibRef | Quantity
1uF | TDK - C1005X5R1E105K050BC - COND, CERÁ MULT, X5R, 1UF, 25V, 0402 | C1, C2, C3, C9 | C0402 | C1005X5R1E105K050BC | 4
100NF | 0402 0.1 uF 16V ±10 % Tolerance X7R SMT Multilayer Ceramic Capacitor | C4, C5, C6, C7, C8, C10, C11, C15 | C0402 | GRM155R71C104KA88D | 8
12PF | CAP CER 12PF 50V C0G/NP0 0402 | C12, C13 | C0402 | 04025A120JAT2A | 2
2.2uF | TDK - C1005X5R1A225K050BC - COND, CERÁ MULT, X5R, 2.2UF, 10V, 0402 | C14 | C0402 | C1005X5R1A225K050BC | 1
BL-HB337A-AV-TRB | Blue 0402 1X.5X4MM | D1 | LED0402-RD | BL-HB337A-AV-TRB | 1
BL-HUB37A-AV-TRB | Red 0402 1X.5X4MM | D2 | LED0402-RD | BL-HUB37A-AV-TRB | 1
5033981892 |  | J1 | 503398-1892_MOL | 5033981892 | 1
920-F62A2021S10101 |  | J2 | MICRO-USB_MICRO-USB-31 | 920-F62A2021S10101 | 1
SI2307CDS-T1-E3 | P-Channel 30 V 3.5A (Tc) 1.1W (Ta), 1.8W (Tc) Surface Mount SOT-23-3 (TO-236) | Q1, Q2 | SOT-23_L2.9-W1.3-P1.90-LS2.4-BR | SI2307CDS-T1-E3 | 2
2N7002KQ-7 | MOSFETs SOT-23 | Q3 | SOT-23_L2.9-W1.3-P1.90-LS2.4-BR | 2N7002KQ-7 | 1
100K | RES SMD 100K OHM 1% 1/16W 0402 | R1, R2 | R0402 | CRCW0402100KFKED | 2
10K | VISHAY DRALORIC - CRCW040210K0FKED - RESISTENCIA, 10K, 0.063W, 1%, 0402, SMD | R3, R4, R5, R6, R7, R8, R9 | R0402 | CRCW040210K0FKED | 7
RC0402FR-0727RL | RES 27 OHM 1% 1/16W 0402 | R10, R11 | R0402 | RC0402FR-0727RL | 2
120R | Res General Purpose Thick Film 0402 120 Ohm 1% 1/16W ±100ppm/°C Molded Paper T/R | R12 | R0402 | RC0402FR-07120RL | 1
220R | SMD Chip Resistor, 220 Ohm, ± 1%, 62.5 mW, 0402 [1005 Metric], Thick Film, General Purpose | R13 | R0402 | RC0402FR-07220RL | 1
1K | VISHAY - CRCW04021K00FKED - RES, PELÍC GRUESA, 1K, 1%, 0.063W, 0402 | R14, R15 | R0402 | CRCW04021K00FKEDC | 2
SKTDLDE010 | Switch Tactile N.O. SPST Rectangular Button Gull Wing 0.05A 12VDC 1.6N SMD T/R | S1 | KEY-SMD_SKTDLDE010 | SKTDLDE010 | 1
AP2112K-3.3TRG1 | IC REG LDO 3.3V 0.6A SOT25 | U1 | SOT95P285X140-5N | AP2112K-3.3TRG1 | 1
RP2040 | RP2040 chip for Raspberry Pi Pico - ARM Cortex-M0+ MCU 32-Bit | U2 | QFN40P700X700X90-57N | RP2040 | 1
W25Q16JVUXIQ | NOR Flash Serial (SPI, Dual SPI, Quad SPI) 3V/3.3V 16M-bit 2M x 8 6ns 8-Pin USON EP T/R | U3 | SON50P300X200X60-9N | W25Q16JVUXIQ | 1
XYDBPCNANF-12MHZ | XYDBPCNANF-12MHZ | X1 | OSC-SMD_4P-L2.5-W2.0-BL | XYDBPCNANF-12MHZ | 1

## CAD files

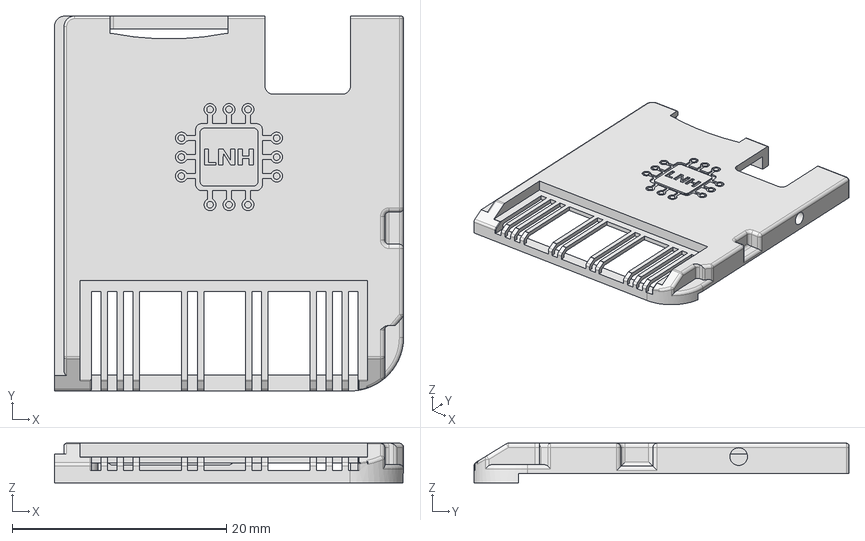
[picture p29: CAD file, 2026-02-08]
dspico-shell/3d-models/v1.5/dspico-shell-bottom_v1-5.step
32.6 x 35.0 x 3.70 mm

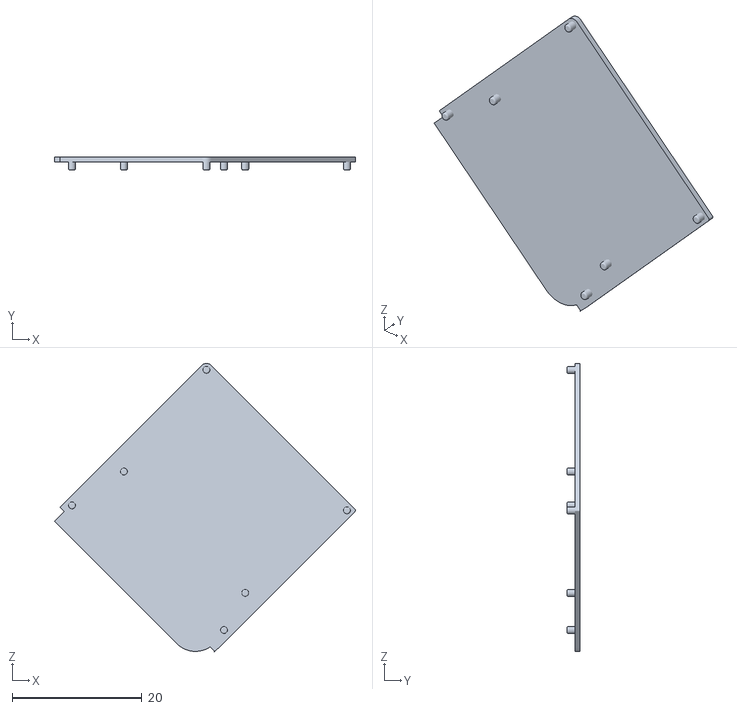
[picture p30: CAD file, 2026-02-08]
dspico-shell/3d-models/v1.5/forced-rotation-printing/dspico-shell-top_v1-5-FR.stl
46.4 x 2.00 x 44.4

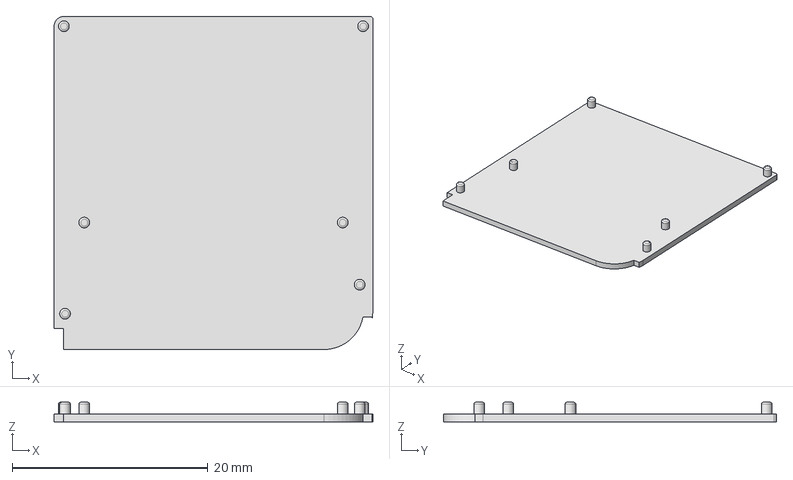
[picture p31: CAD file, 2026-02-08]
dspico-shell/3d-models/v1.5/dspico-shell-top_v1-5.step
32.6 x 34.0 x 2.00 mm

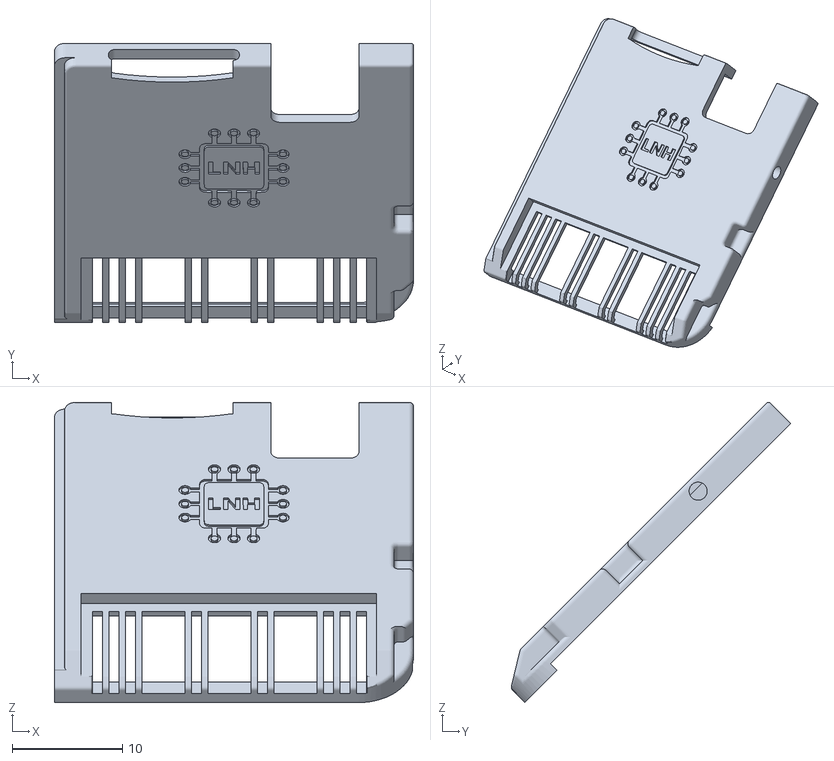
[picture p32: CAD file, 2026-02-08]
dspico-shell/3d-models/v1.5/forced-rotation-printing/dspico-shell-bottom_v1-5-FR.stl
32.6 x 25.4 x 27.3

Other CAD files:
dspico-shell/3d-models/v1.5/forced-rotation-printing/dspico-shell-top-DEV_v1-5-FR.stl
dspico-shell/3d-models/v1.5/dspico-shell-top-DEV_v1-5.step
dspico-shell/3d-models/v1.4/dspico-shell-top-DEV-v1-4.stp
dspico-shell/3d-models/v1.4/forced-rotation-printing/dspico-shell-top_v1-4-FR.stl
dspico-shell/3d-models/v1.4/dspico-shell-bottom_v1-4.stp
dspico-shell/3d-models/v1.4/forced-rotation-printing/dspico-shell-top-DEV_v1-4-FR.stl
dspico-shell/3d-models/v1.4/dspico-shell-top_v1-4.stp
dspico-shell/3d-models/v1.4/forced-rotation-printing/dspico-shell-bottom_v1-4-FR.stl
dspico-shell/3d-models/v1.4/dspico-shell-bottom_v1-4.stl
dspico-shell/3d-models/v1.4/dspico-shell-top-DEV_v1-4.stl
dspico-shell/3d-models/v1.4/dspico-shell-top_v1-4.stl
dspico-shell/3d-models/v1.5/dspico-shell-bottom_v1-5.stl
dspico-shell/3d-models/v1.5/dspico-shell-top-DEV_v1-5.stl
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

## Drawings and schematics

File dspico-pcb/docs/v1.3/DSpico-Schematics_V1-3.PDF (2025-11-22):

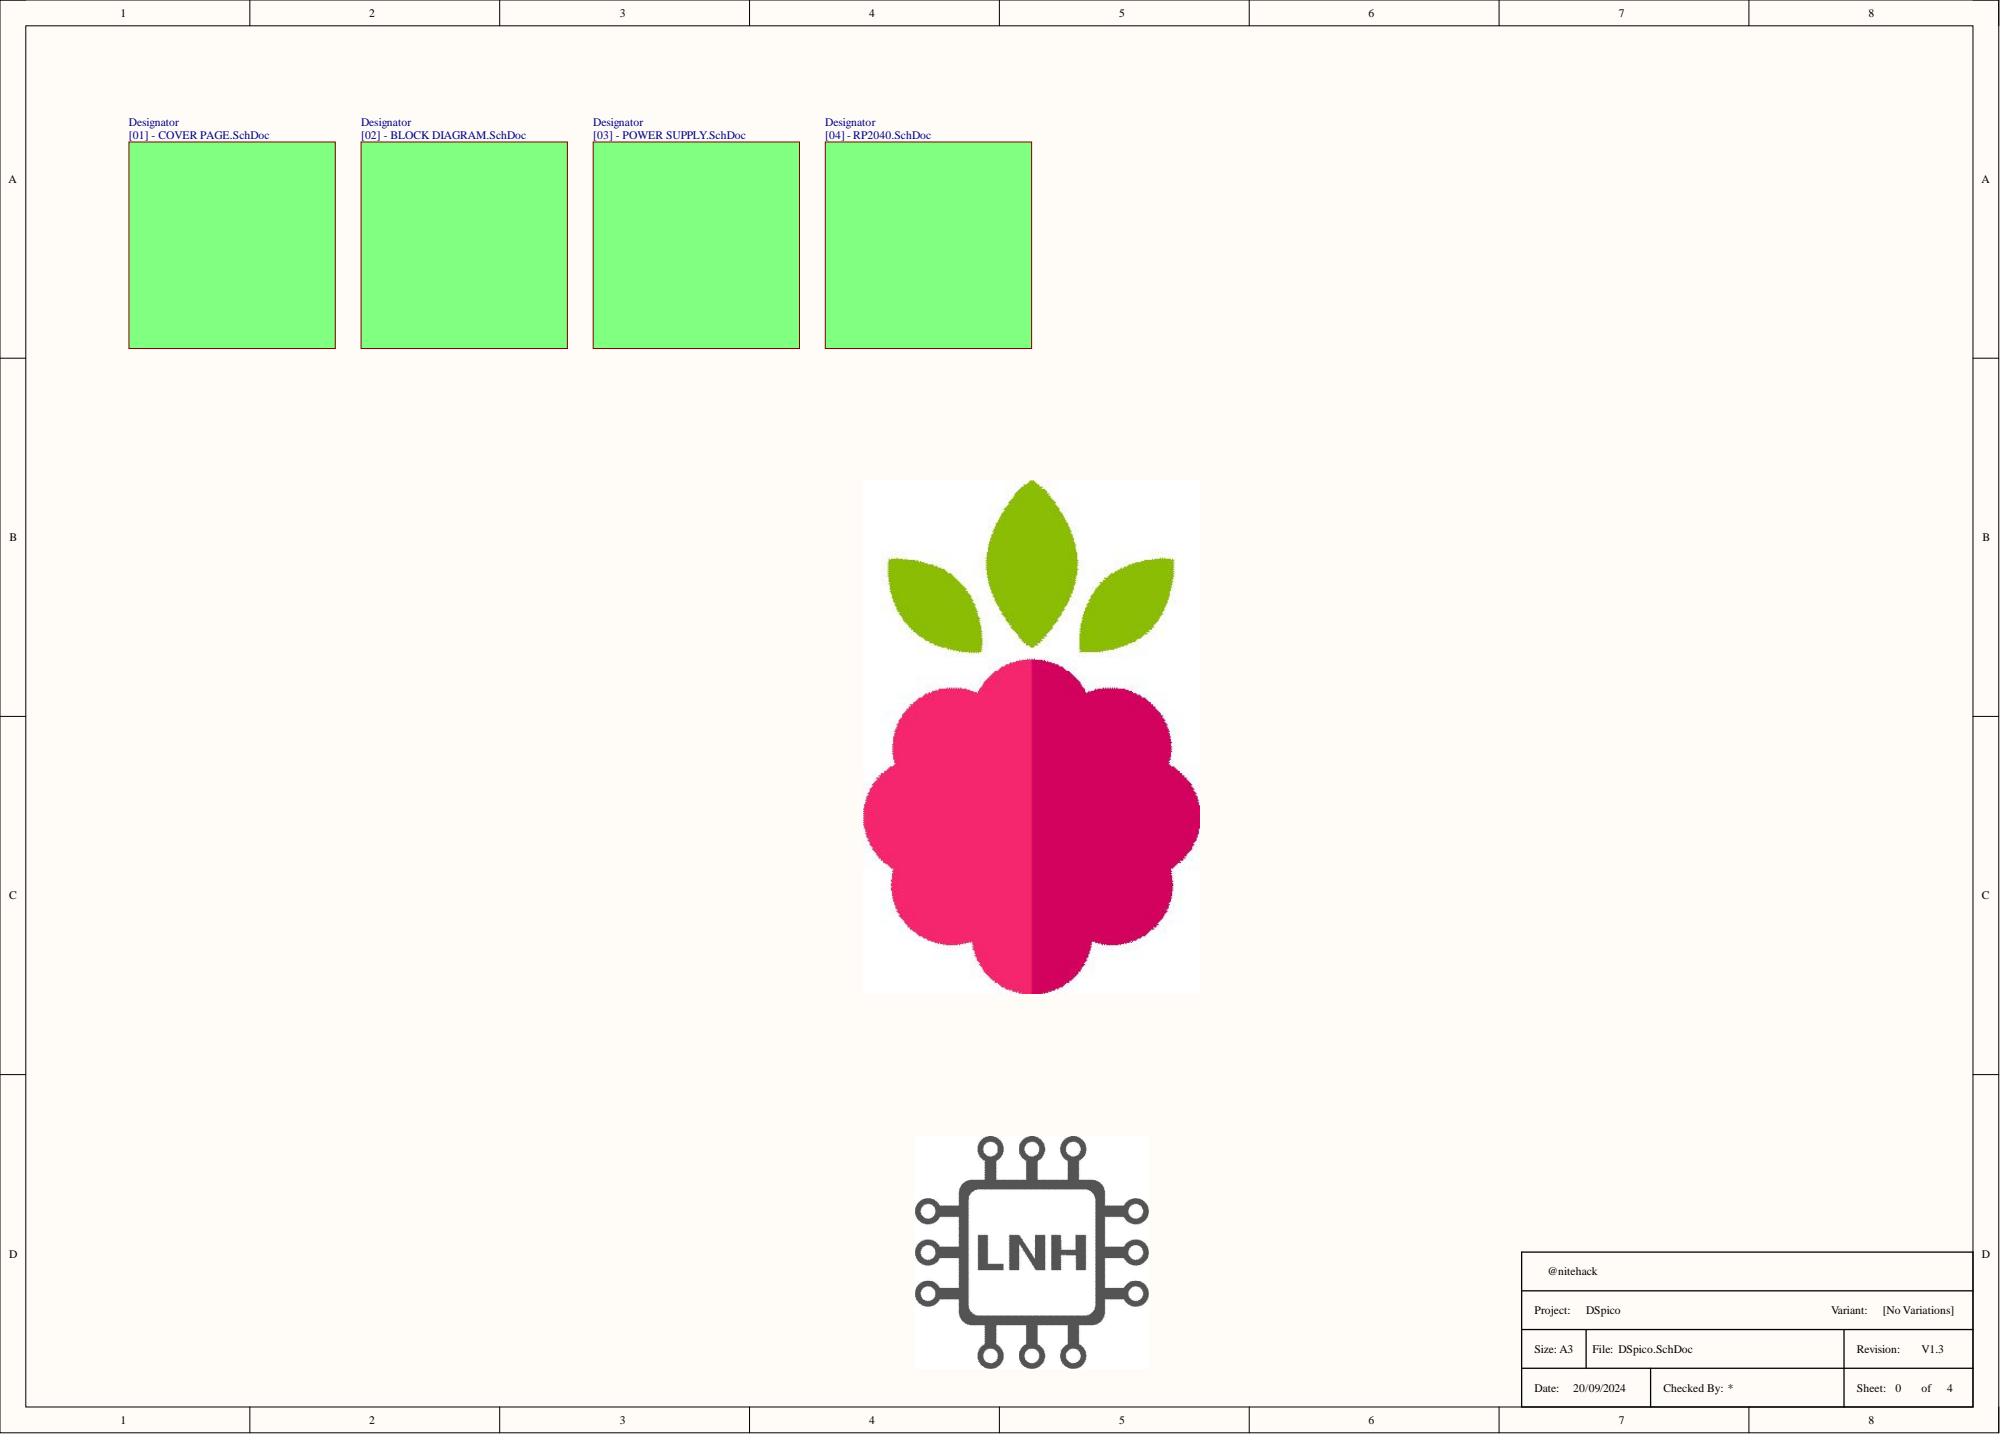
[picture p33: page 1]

Size: A3 | File: DSpico.SchDoc | Revision: V1.3

Date: 20/09/2024 | Checked By: * | Sheet: 0 of 4

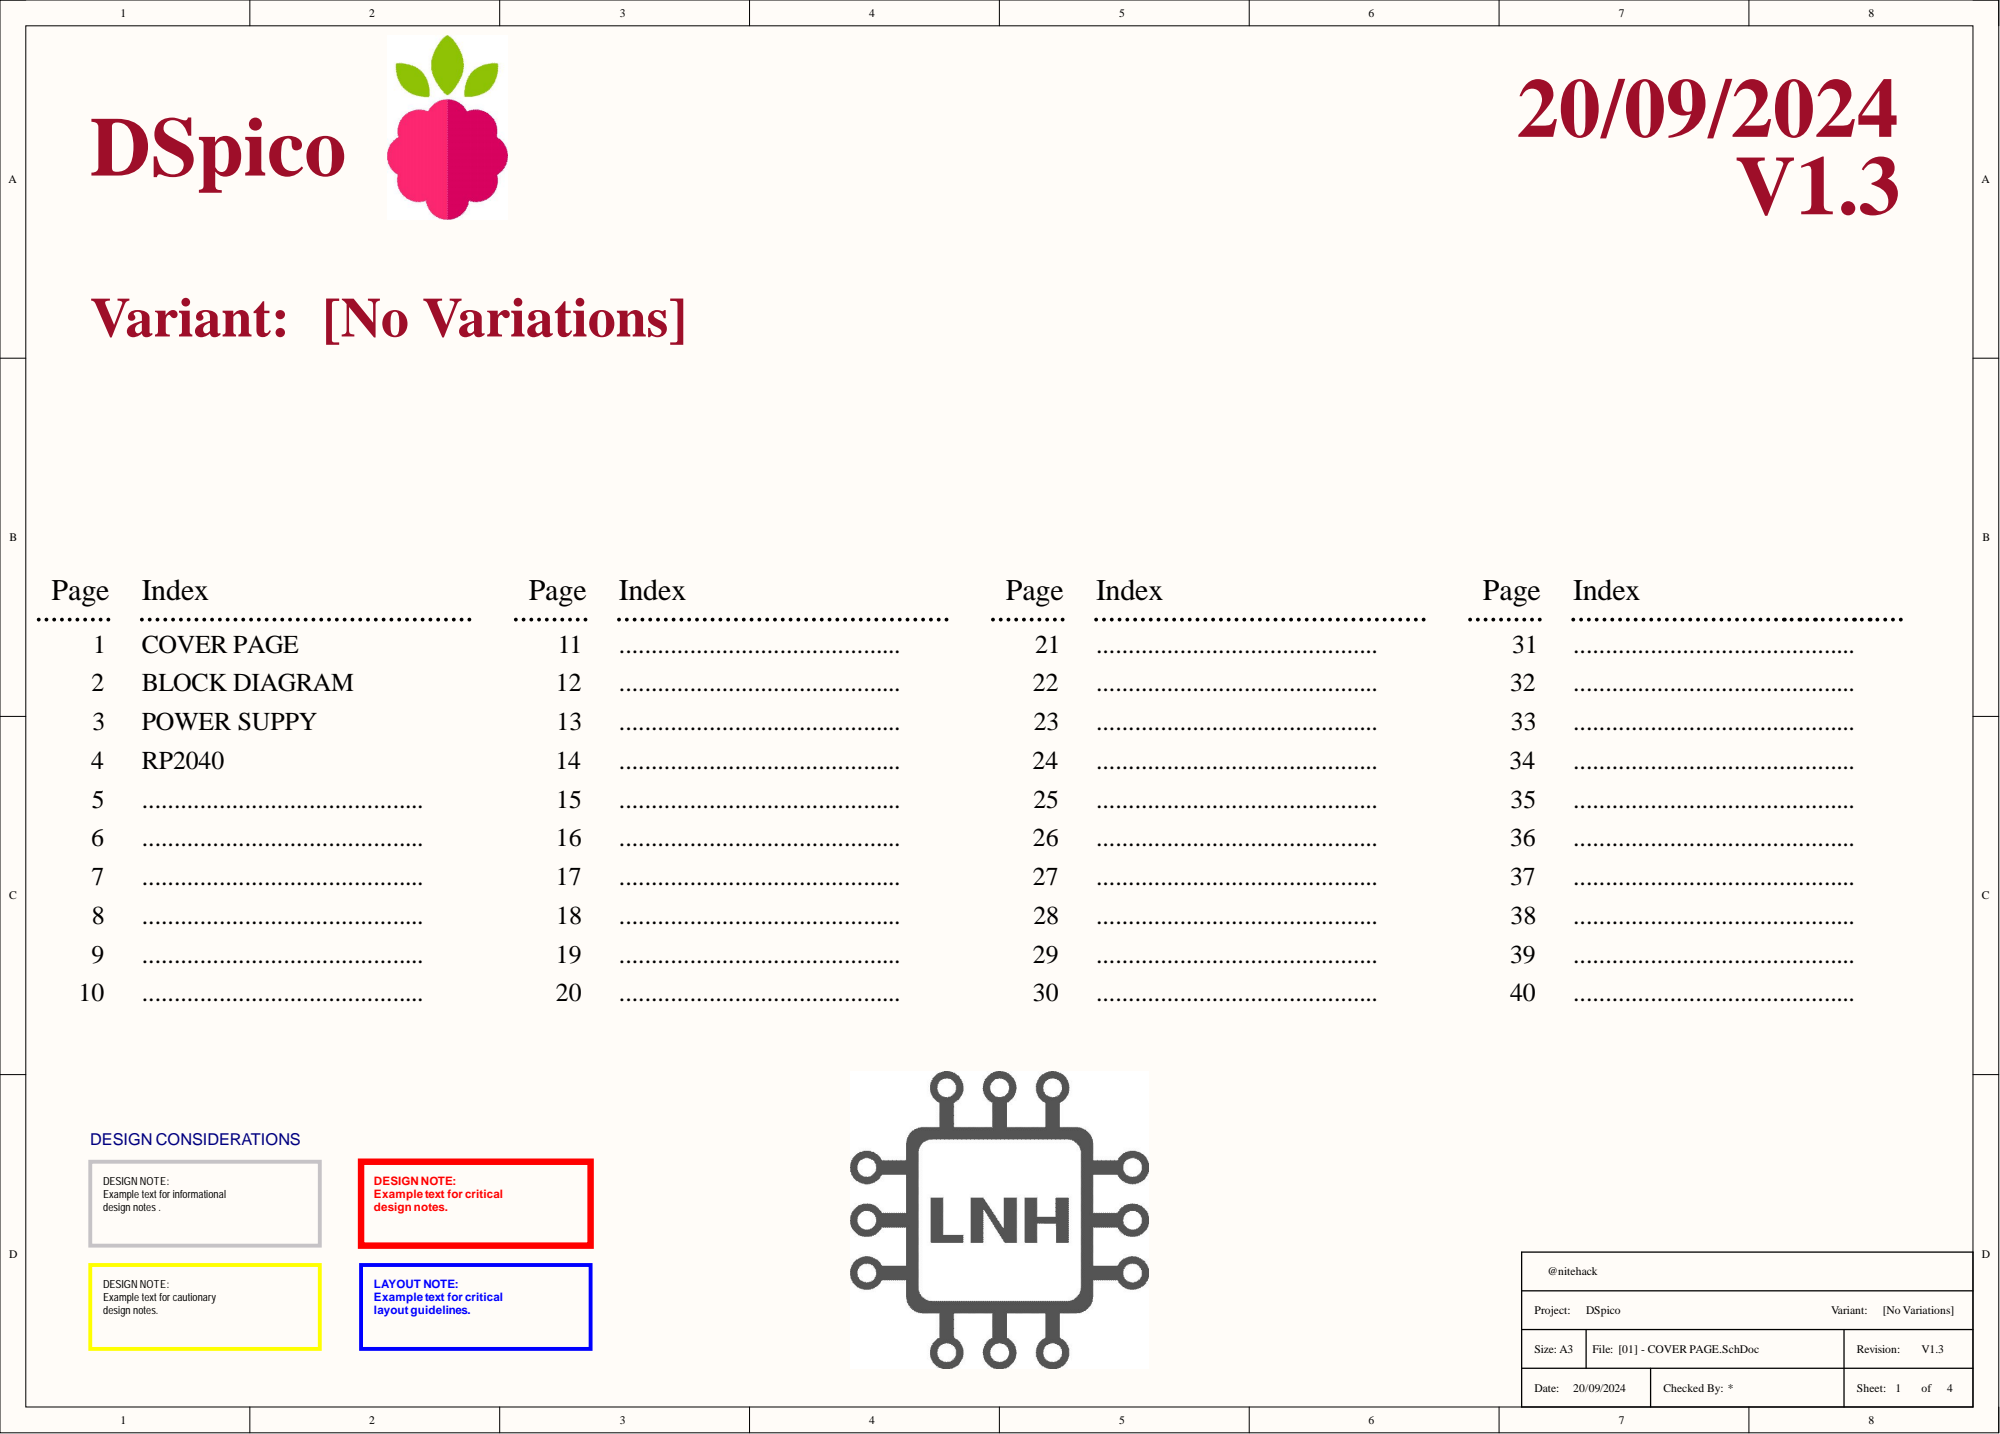
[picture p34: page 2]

DESIGN NOTE:
Example text for informational
design notes .

Example text for critical
design notes.

Example text for cautionary

LAYOUT NOTE:

[01] - COVER PAGE.SchDoc | V1.3

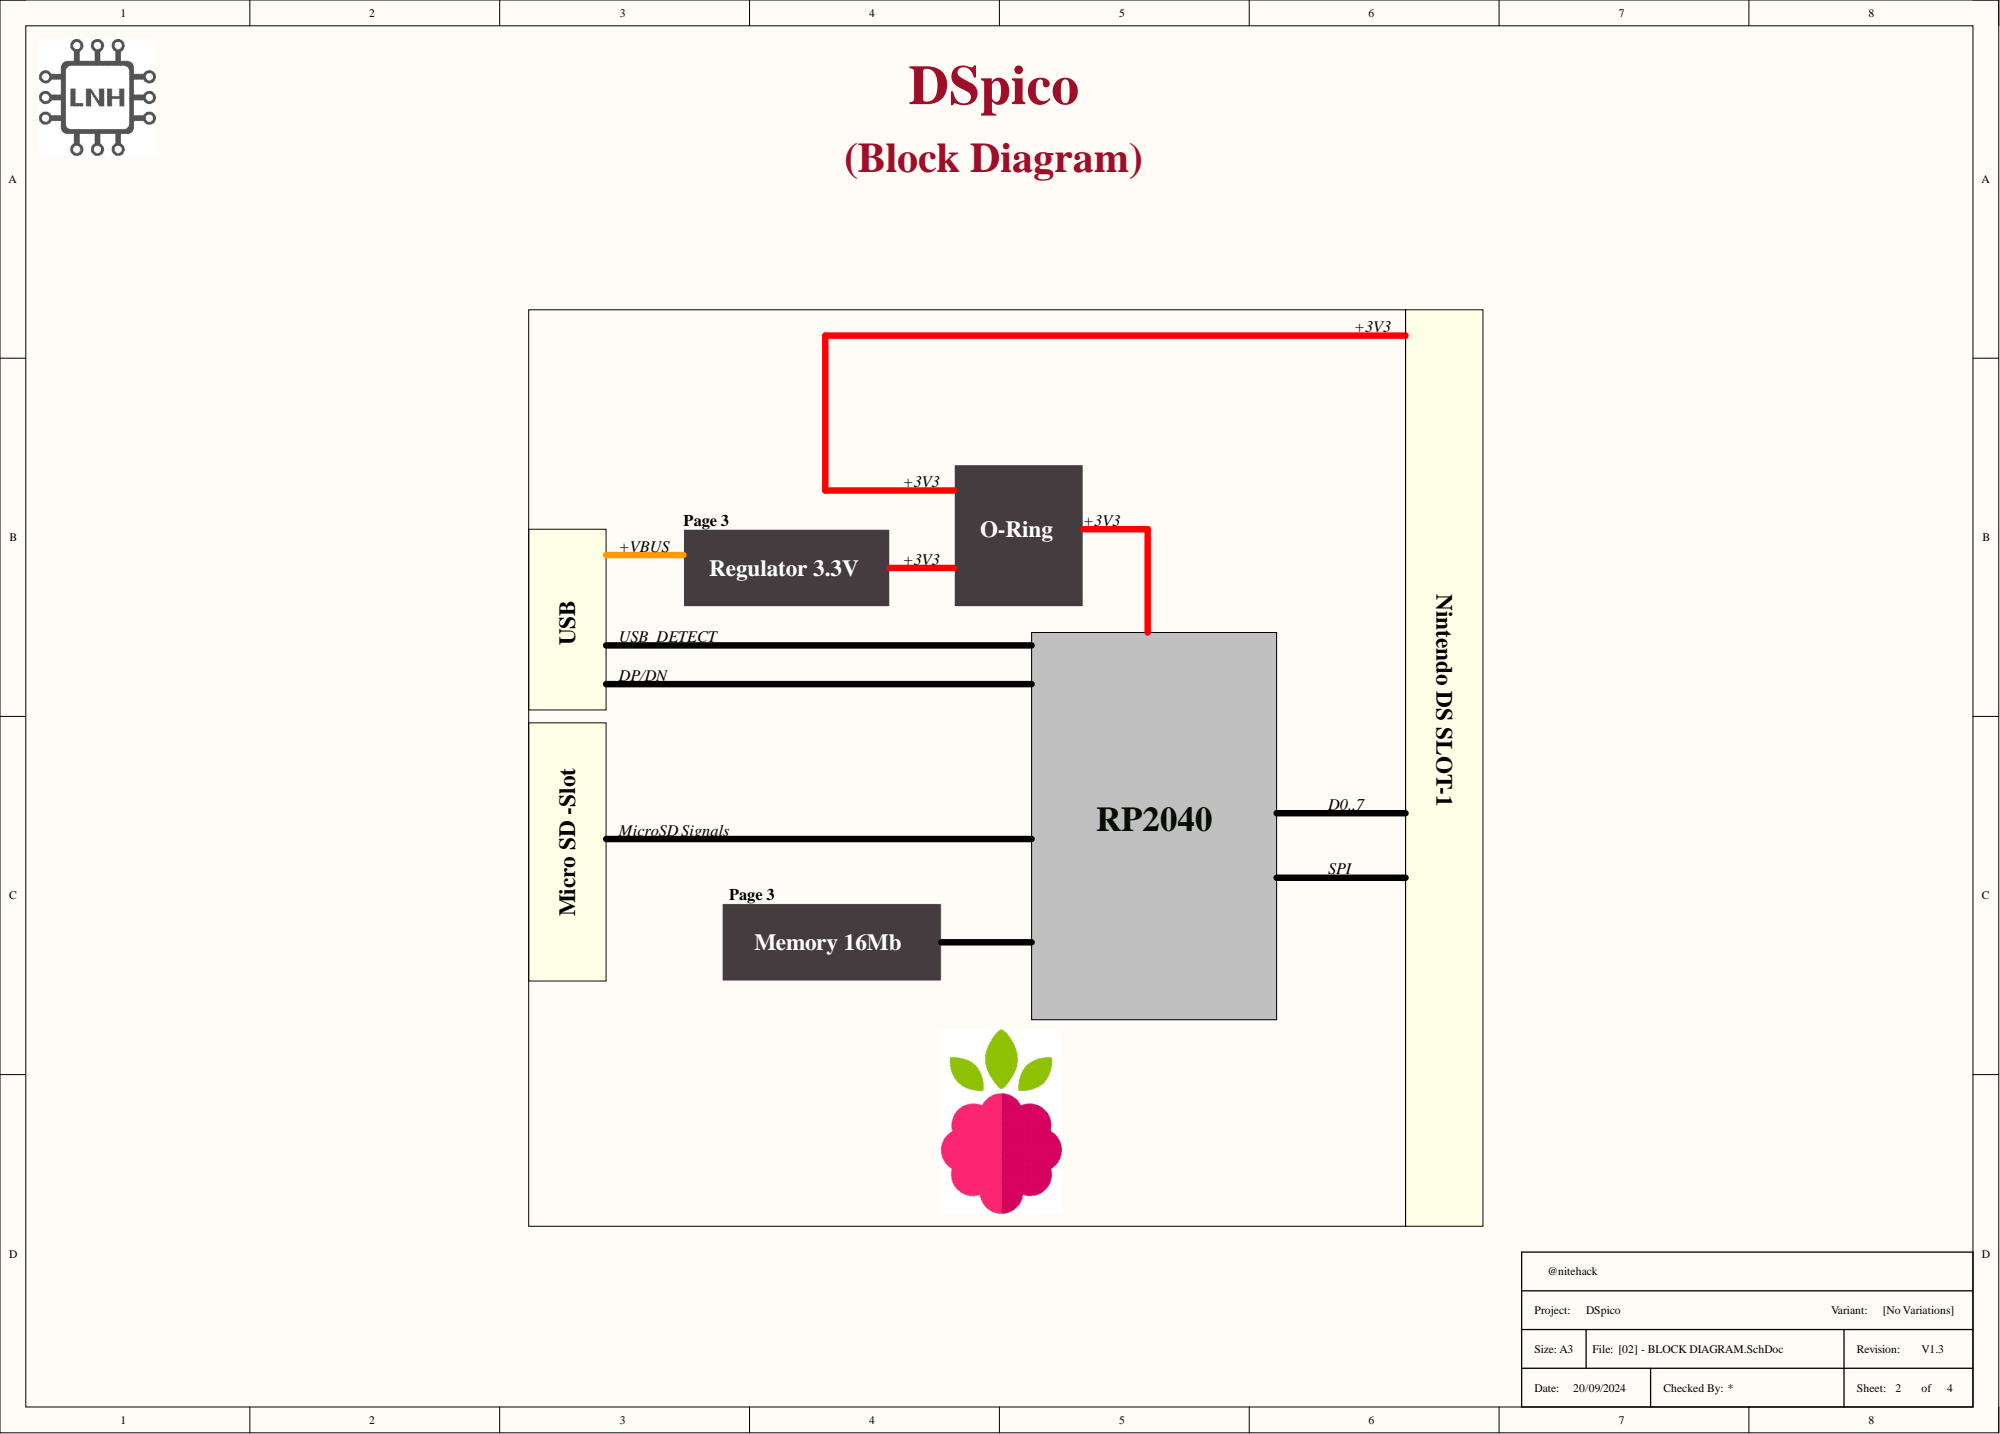
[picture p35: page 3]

[02] - BLOCK DIAGRAM.SchDoc | V1.3

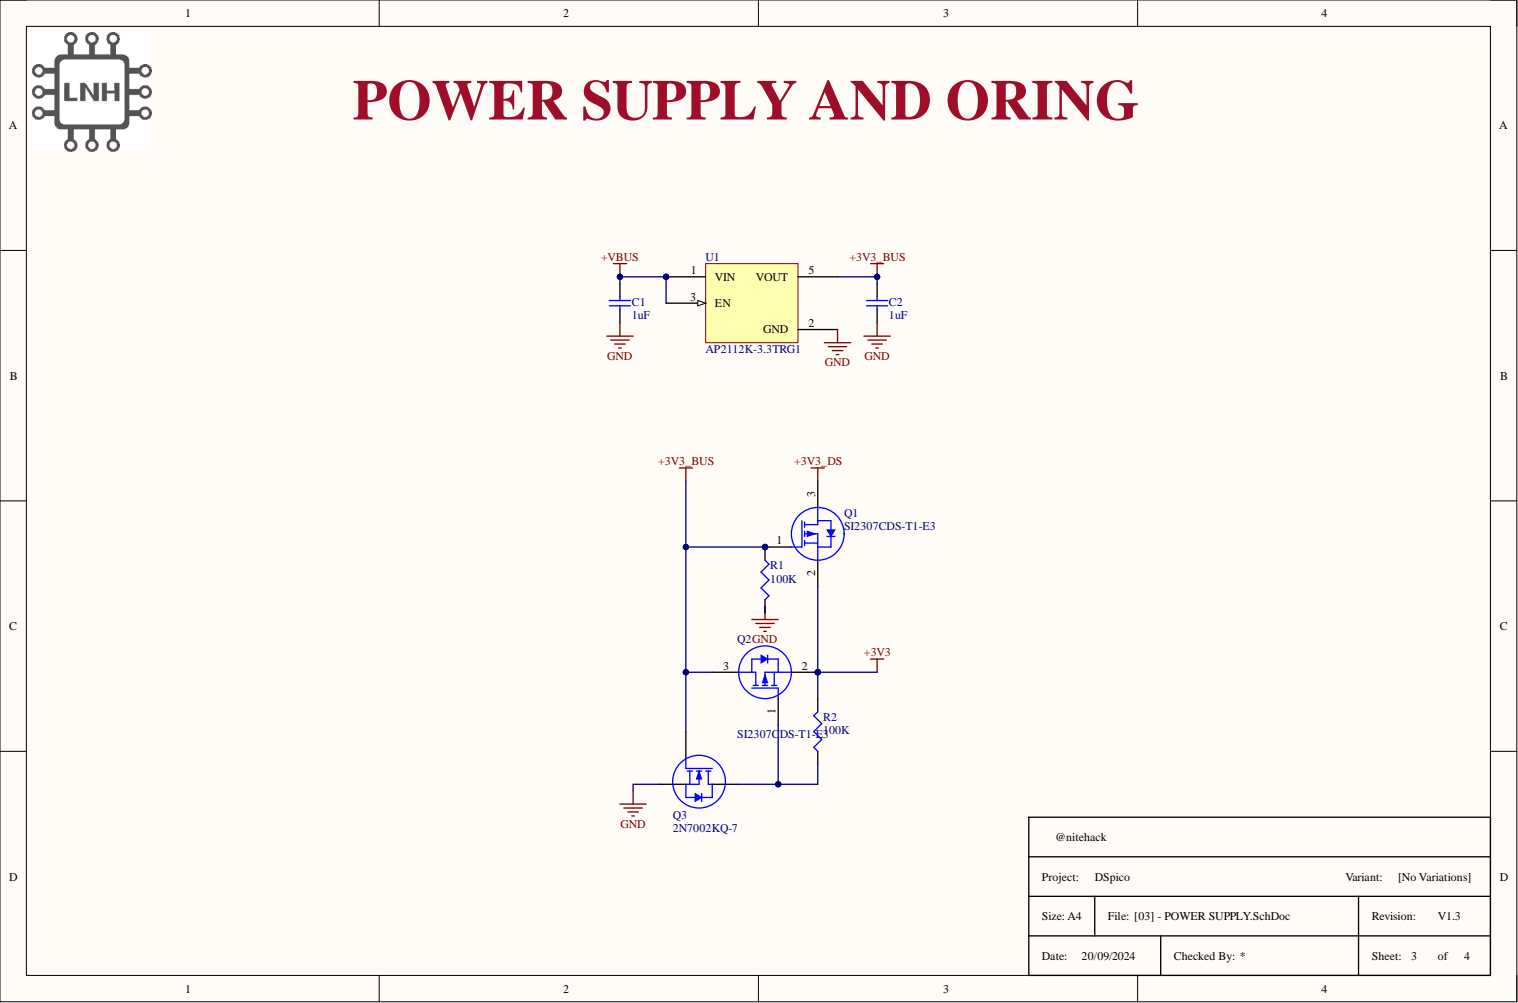
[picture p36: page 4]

POWER SUPPLY AND ORING

Size: A4 | File: [03] - POWER SUPPLY.SchDoc | Revision: V1.3

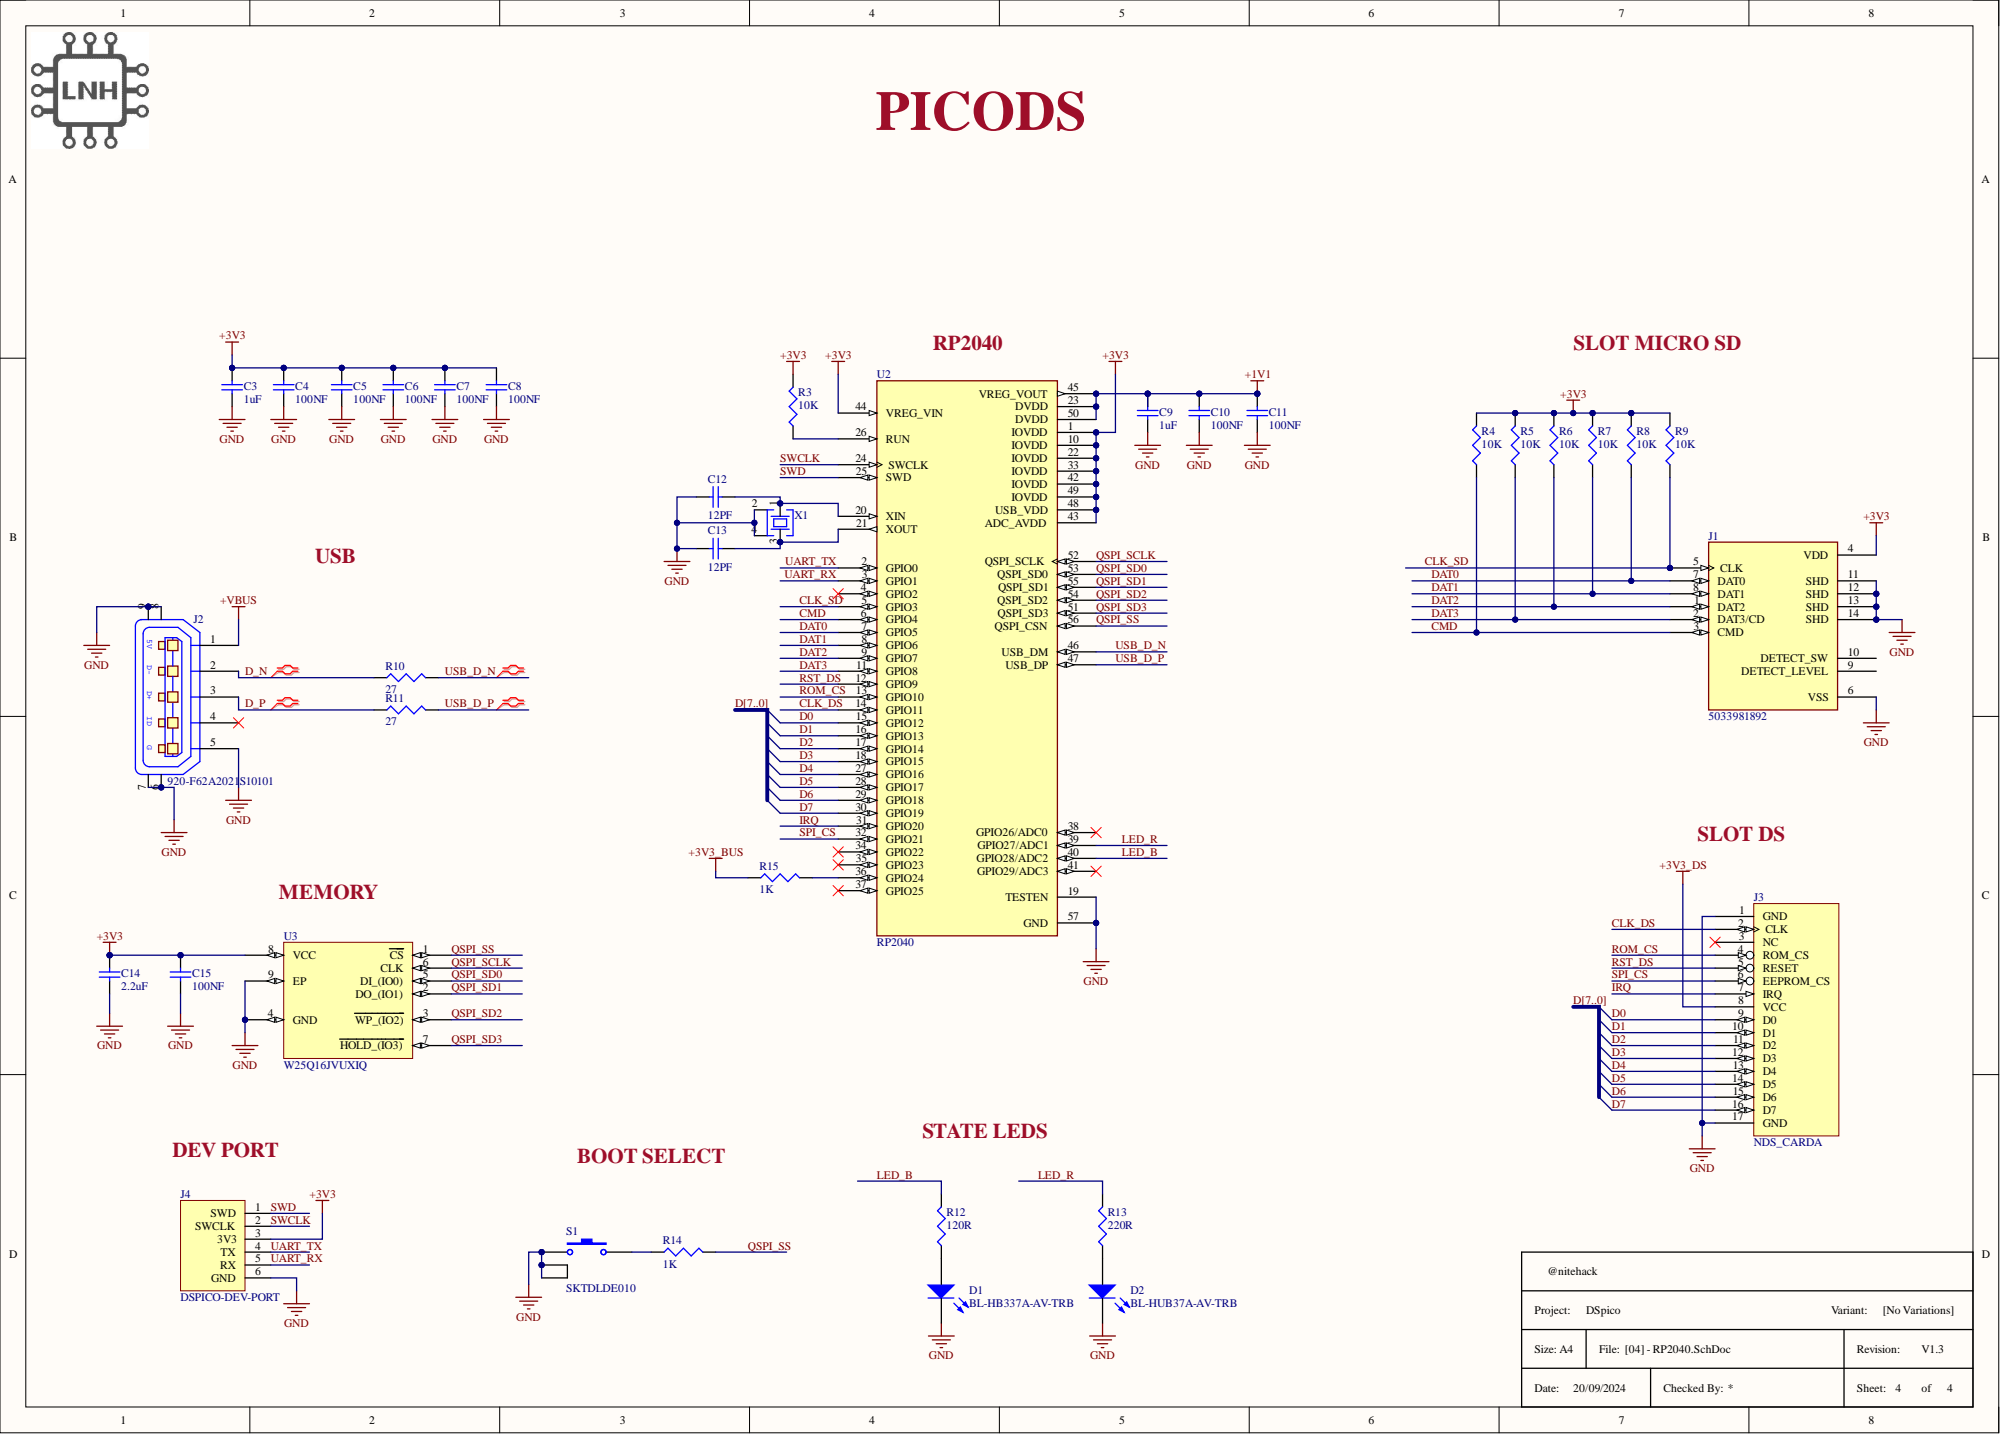
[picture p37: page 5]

Size: A 4 | Fi le: 4] - RP2 0.Sch D o c | Rev i s i o n : V .

/ / | Checked By : * | Sheet : o f

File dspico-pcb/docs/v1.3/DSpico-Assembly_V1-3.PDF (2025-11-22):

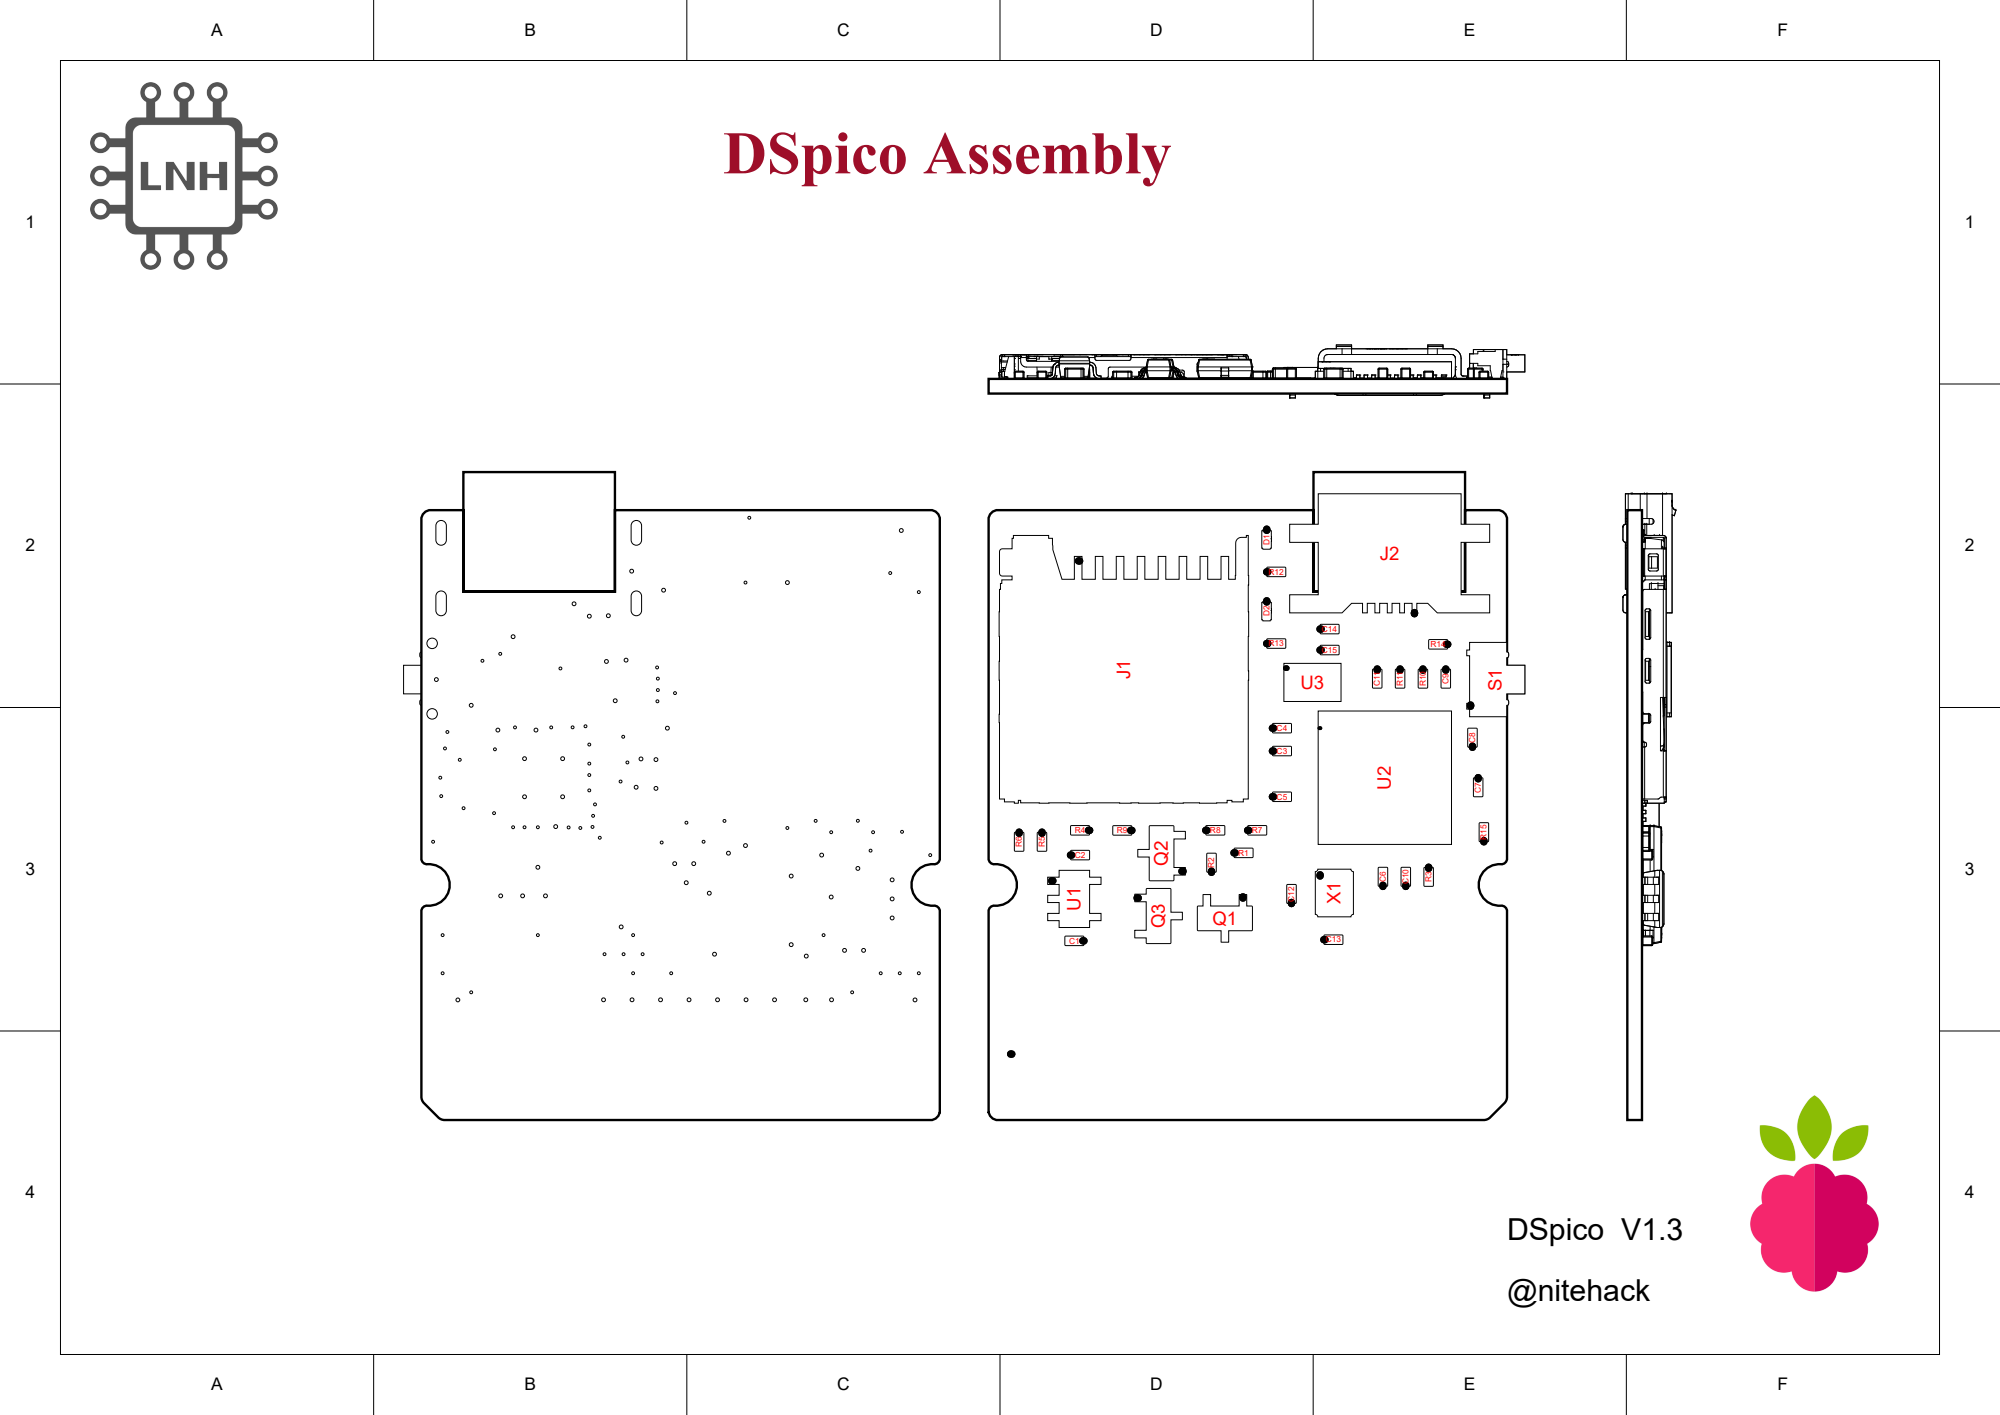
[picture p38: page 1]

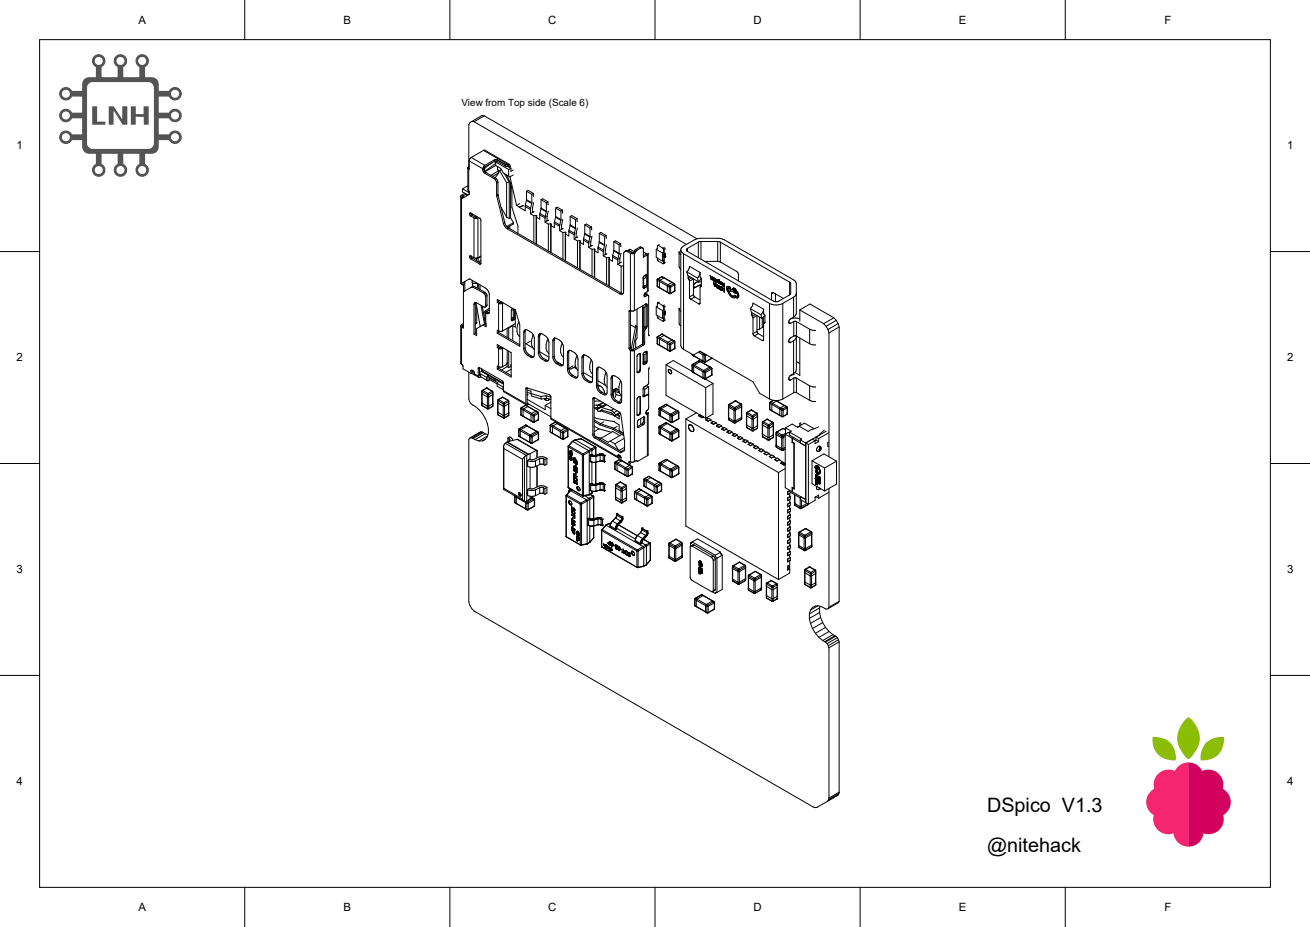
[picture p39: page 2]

View from Top side (Scale 6)

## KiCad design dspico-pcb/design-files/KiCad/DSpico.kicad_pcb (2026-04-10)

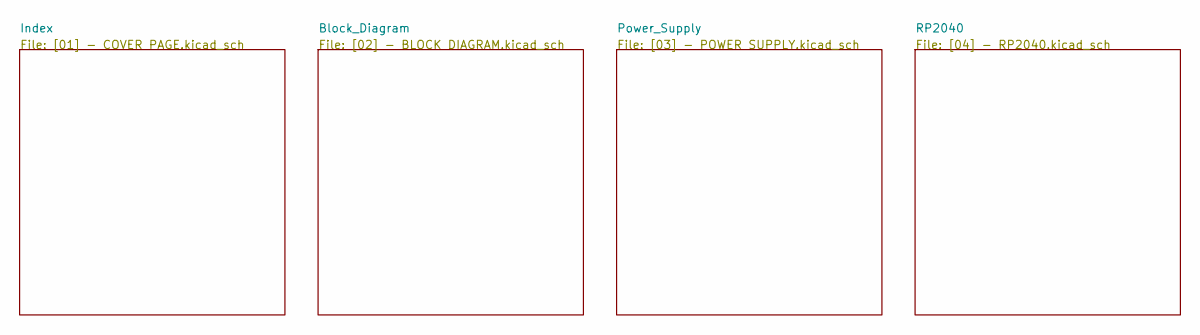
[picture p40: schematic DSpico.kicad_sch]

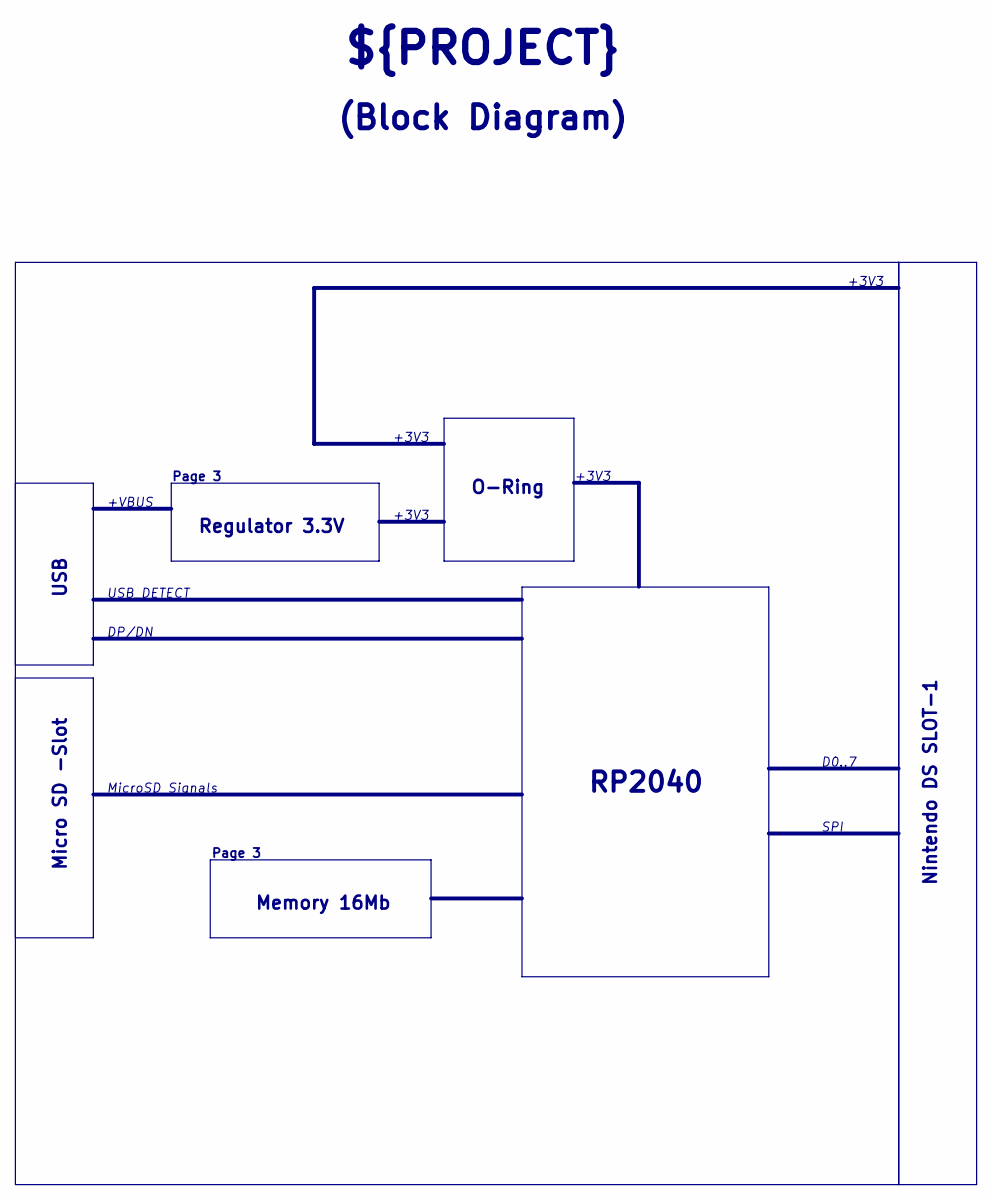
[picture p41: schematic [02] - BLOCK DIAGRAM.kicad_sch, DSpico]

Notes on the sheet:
+VBUS
+3V3
RP2040
Page 3
(Block Diagram)
USB_DETECT
D0..7
SPI
O-Ring
USB
MicroSD Signals
Regulator 3.3V
Nintendo DS SLOT-1
DP/DN
${PROJECT}
Micro SD -Slot
Memory 16Mb

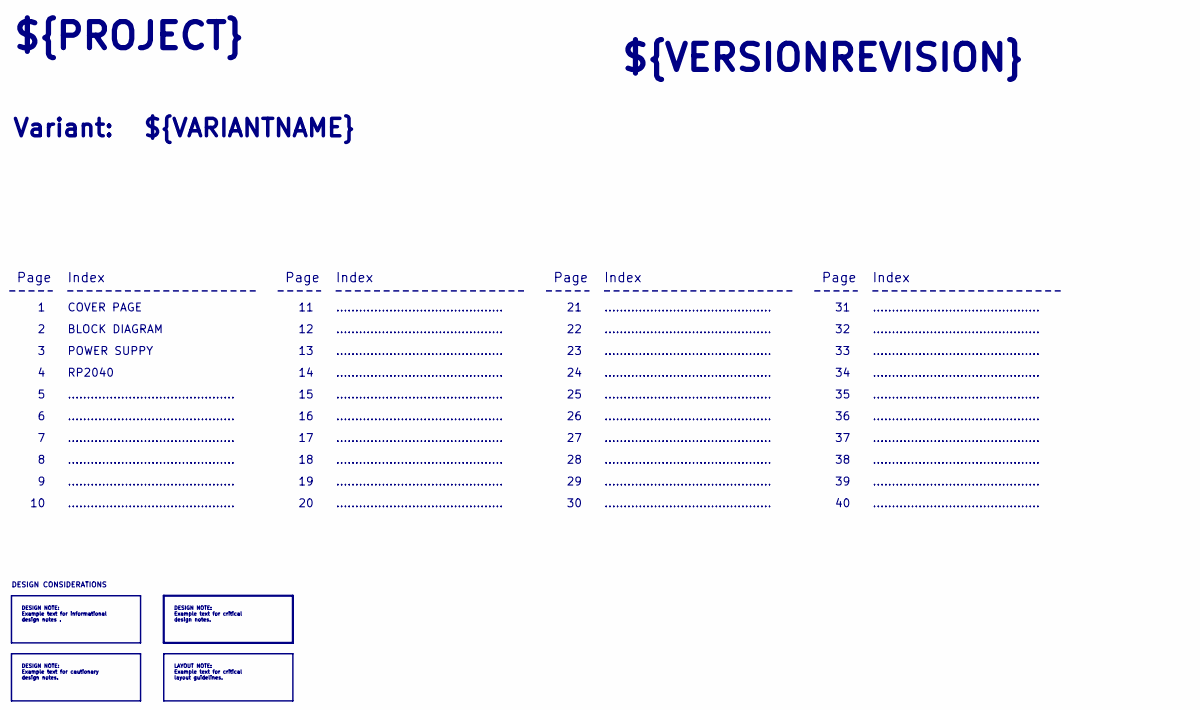
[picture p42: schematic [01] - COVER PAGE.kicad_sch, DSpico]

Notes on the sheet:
Page
............................................
POWER SUPPY
COVER PAGE
${VARIANTNAME}
Index
BLOCK DIAGRAM
${PROJECT}
DESIGN CONSIDERATIONS
RP2040
${VERSIONREVISION}
Variant:
DESIGN NOTE: Example text for cautionary design notes.
DESIGN NOTE: Example text for informational design notes .
DESIGN NOTE: Example text for critical design notes.
LAYOUT NOTE: Example text for critical layout guidelines.

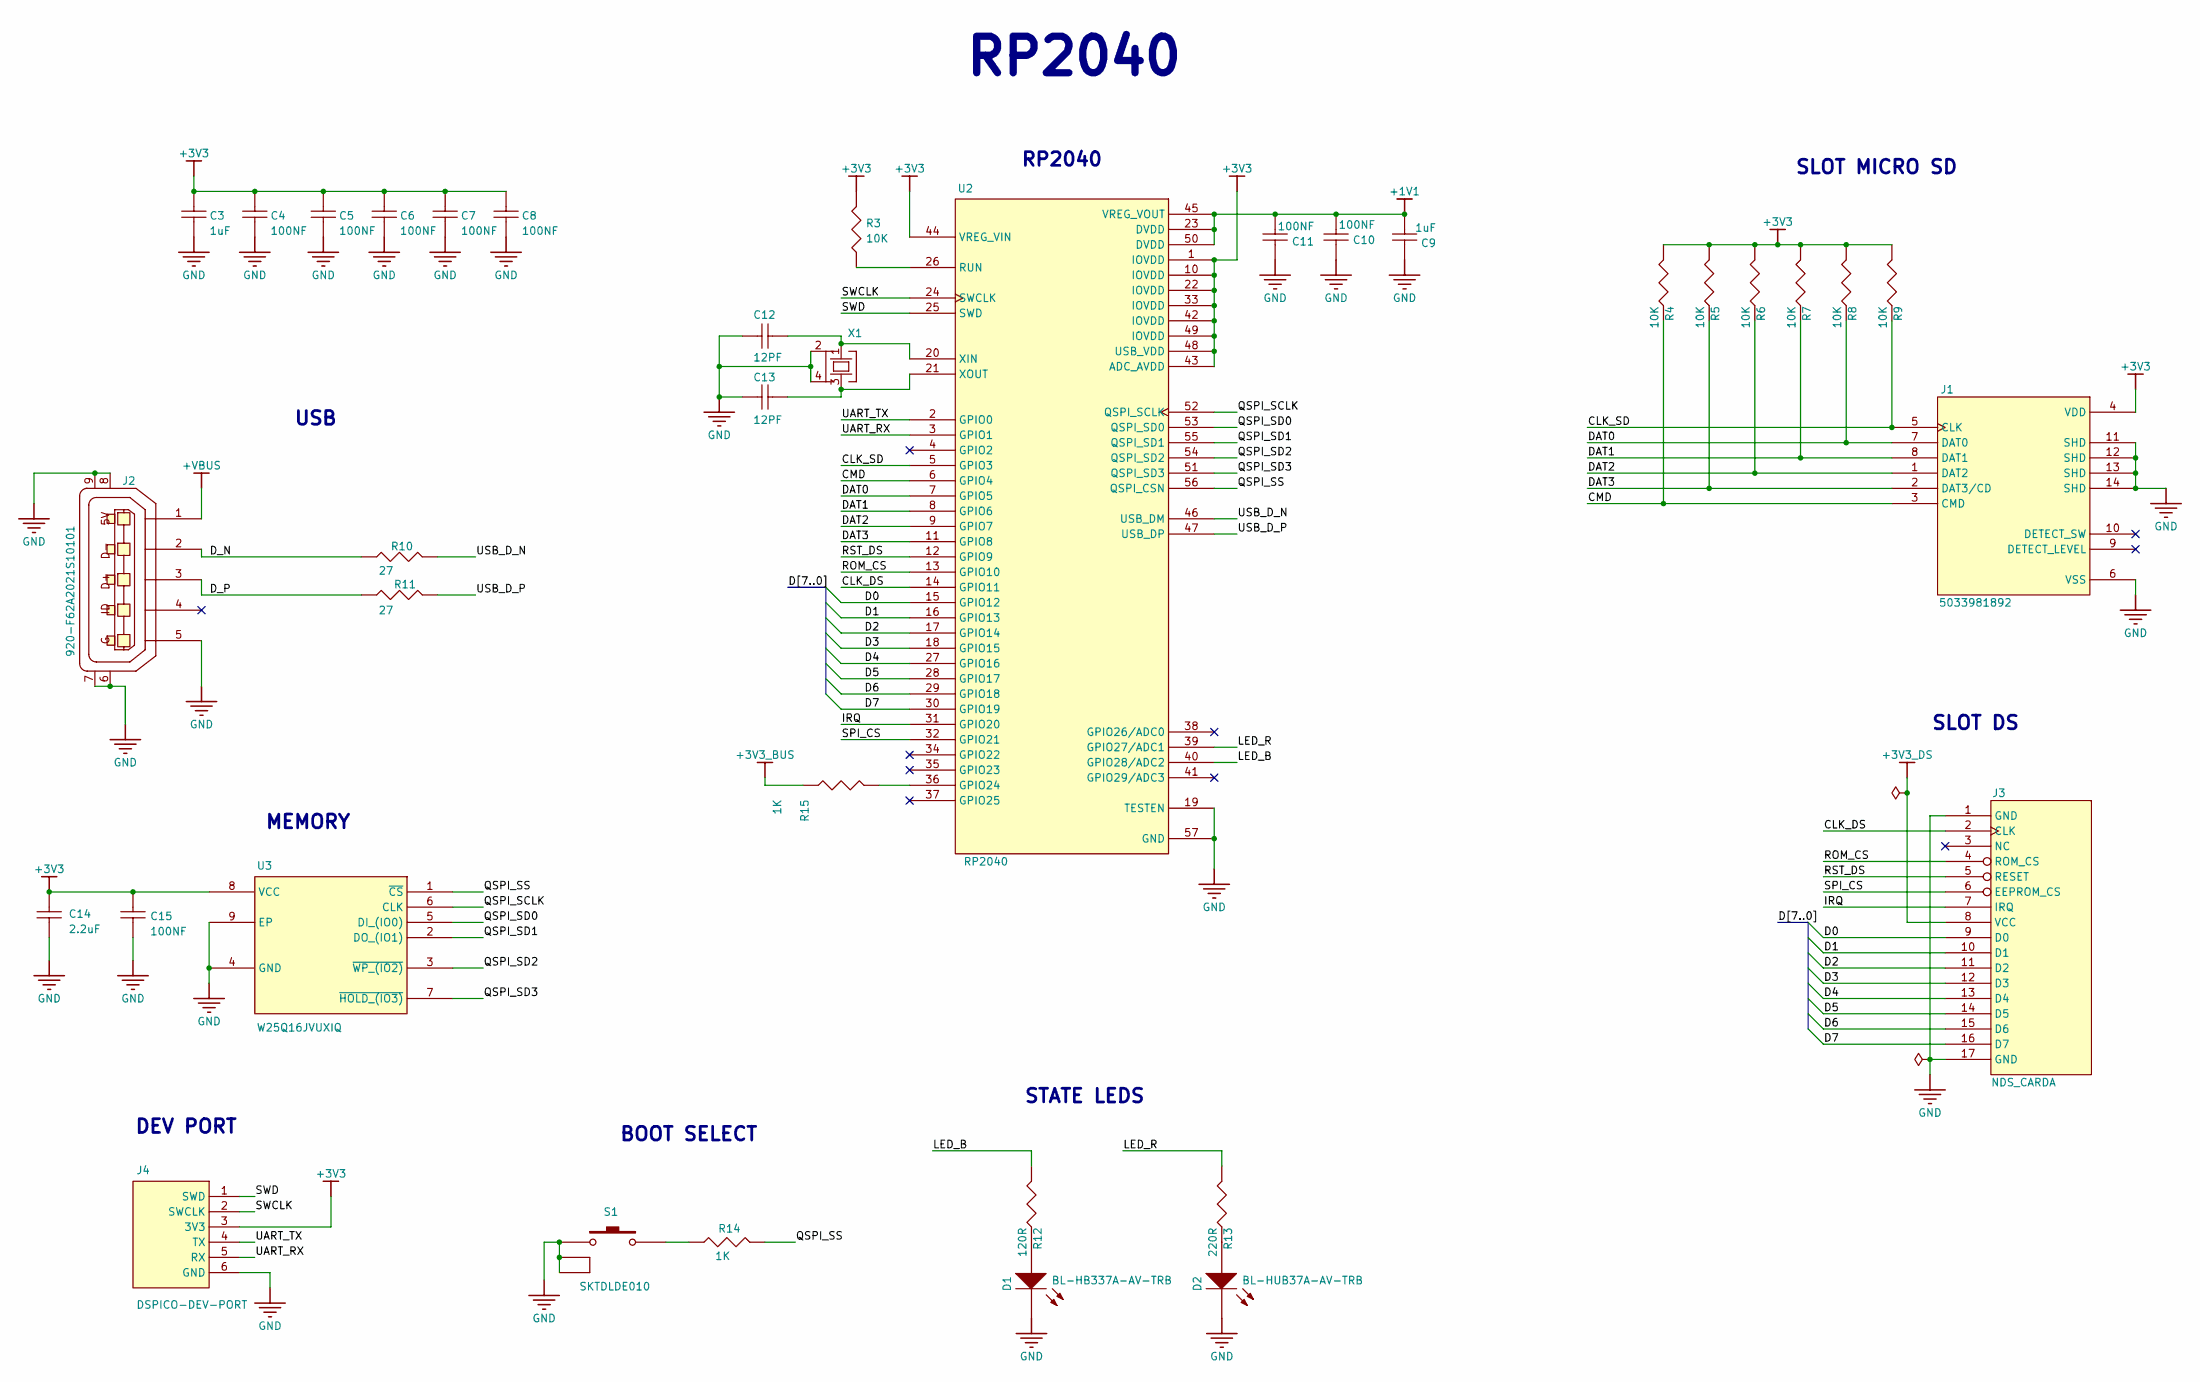
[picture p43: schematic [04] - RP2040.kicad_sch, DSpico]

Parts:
C3, C9: 1uF; C0402; TOLERANCE 10%; VOLTAGE RATING 25V; MANUFACTURER PART NUMBER C1005X5R1E105K050BC
C4, C5, C6, C7, C8, C10, C11, C15: 100NF; C0402; TOLERANCE 10%; VOLTAGE RATING 16V; MANUFACTURER PART NUMBER GRM155R71C104KA88D
C12, C13: 12PF; C0402; TOLERANCE 5%; VOLTAGE RATING 50V; MANUFACTURER PART NUMBER 04025A120JAT2A
C14: 2.2uF; C0402; MANUFACTURER PART NUMBER C1005X5R1A225K050BC
D1: BL-HB337A-AV-TRB; LED0402-RD; FORWARD VOLTAGE 2.8V; MANUFACTURER PART NUMBER BL-HB337A-AV-TRB
D2: BL-HUB37A-AV-TRB; LED0402-RD; FORWARD VOLTAGE 2V; MANUFACTURER PART NUMBER BL-HUB37A-AV-TRB
J1: 5033981892; 503398-1892_MOL
J2: 920-F62A2021S10101; MICRO-USB_MICRO-USB-31
J3: NDS_CARDA; NDS_CARD
J4: DSPICO-DEV-PORT; EP_DEV_PORT; CURRENT RATING ?; VOLTAGE RATING 3.3V; MANUFACTURER PART NUMBER PICO-DEVELOP-PORT
R3, R4, R5, R6, R7, R8, R9: 10K; R0402; TOLERANCE 1%; POWER RATING 63mW; MANUFACTURER PART NUMBER CRCW040210K0FKED
R10, R11: RC0402FR-0727RL; R0402; WORKING VOLTAGE 50V; TOLERANCE 1%
R12: 120R; R0402; VOLTAGE RATING 50V; POWER RATING 62.5mW; MANUFACTURER PART NUMBER RC0402FR-07120RL
R13: 220R; R0402; VOLTAGE RATING 50V; POWER RATING 62.5mW; MANUFACTURER PART NUMBER RC0402FR-07220RL
R14, R15: 1K; R0402; TOLERANCIA DE RESISTENC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 ± 1%; MANUFACTURER PART NUMBER CRCW04021K00FKED
S1: SKTDLDE010; KEY-SMD_SKTDLDE010; MANUFACTURER PART NUMBER SKTDLDE010
U2: RP2040; QFN40P700X700X90-57N
U3: W25Q16JVUXIQ; SON50P300X200X60-9N
X1: XYDBPCNANF-12MHZ; OSC-SMD_4P-L2.5-W2.0-BL

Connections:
+1V1: C9.2, C10.2, C11.2, U2.23 (DVDD), U2.45 (VREG_VOUT), U2.50 (DVDD)
+3V3: C3.2, C4.2, C5.2, C6.2, C7.2, C8.2, C14.2, C15.2, J1.4 (VDD), J4.3 (3V3), R3.2, R4.2, R5.2, R6.2, R7.2, R8.2, R9.2, U2.1 (IOVDD), U2.10 (IOVDD), U2.22 (IOVDD), U2.33 (IOVDD), U2.42 (IOVDD), U2.43 (ADC_AVDD), U2.44 (VREG_VIN), U2.48 (USB_VDD), U2.49 (IOVDD), U3.8 (VCC); also elsewhere on the board
+3V3_BUS: R15.1; also elsewhere on the board
+3V3_DS: J3.8 (VCC); also elsewhere on the board
+VBUS: J2.1; also elsewhere on the board
/RP2040/CLK_DS: J3.2 (CLK), U2.14 (GPIO11)
/RP2040/CLK_SD: J1.5 (CLK), R9.1, U2.5 (GPIO3)
/RP2040/CMD: J1.3 (CMD), R4.1, U2.6 (GPIO4)
/RP2040/D0: J3.9 (D0), U2.15 (GPIO12)
/RP2040/D1: J3.10 (D1), U2.16 (GPIO13)
/RP2040/D2: J3.11 (D2), U2.17 (GPIO14)
/RP2040/D3: J3.12 (D3), U2.18 (GPIO15)
/RP2040/D4: J3.13 (D4), U2.27 (GPIO16)
/RP2040/D5: J3.14 (D5), U2.28 (GPIO17)
/RP2040/D6: J3.15 (D6), U2.29 (GPIO18)
/RP2040/D7: J3.16 (D7), U2.30 (GPIO19)
/RP2040/DAT0: J1.7 (DAT0), R8.1, U2.7 (GPIO5)
/RP2040/DAT1: J1.8 (DAT1), R7.1, U2.8 (GPIO6)
/RP2040/DAT2: J1.1 (DAT2), R6.1, U2.9 (GPIO7)
/RP2040/DAT3: J1.2 (DAT3/CD), R5.1, U2.11 (GPIO8)
/RP2040/D_N: J2.2, R10.1
/RP2040/D_P: J2.3, R11.1
/RP2040/IRQ: J3.7 (IRQ), U2.31 (GPIO20)
/RP2040/LED_B: R12.2, U2.40 (GPIO28/ADC2)
/RP2040/LED_R: R13.2, U2.39 (GPIO27/ADC1)
/RP2040/QSPI_SCLK: U2.52 (QSPI_SCLK), U3.6 (CLK)
/RP2040/QSPI_SD0: U2.53 (QSPI_SD0), U3.5 (DI_(IO0))
/RP2040/QSPI_SD1: U2.55 (QSPI_SD1), U3.2 (DO_(IO1))
/RP2040/QSPI_SD2: U2.54 (QSPI_SD2), U3.3 (~WP_(IO2))
/RP2040/QSPI_SD3: U2.51 (QSPI_SD3), U3.7 (~HOLD_(IO3))
/RP2040/QSPI_SS: R14.2, U2.56 (QSPI_CSN), U3.1 (~CS)
/RP2040/ROM_CS: J3.4 (ROM_CS), U2.13 (GPIO10)
/RP2040/RST_DS: J3.5 (RESET), U2.12 (GPIO9)
/RP2040/SPI_CS: J3.6 (EEPROM_CS), U2.32 (GPIO21)
/RP2040/SWCLK: J4.2 (SWCLK), U2.24 (SWCLK)
/RP2040/SWD: J4.1 (SWD), U2.25 (SWD)
/RP2040/UART_RX: J4.5 (RX), U2.3 (GPIO1)
/RP2040/UART_TX: J4.4 (TX), U2.2 (GPIO0)
/RP2040/USB_D_N: R10.2, U2.46 (USB_DM)
/RP2040/USB_D_P: R11.2, U2.47 (USB_DP)
GND: C3.1, C4.1, C5.1, C6.1, C7.1, C8.1, C9.1, C10.1, C11.1, C12.1, C13.1, C14.1, C15.1, D1.1, D2.1, J1.6 (VSS), J1.11 (SHD), J1.12 (SHD), J1.13 (SHD), J1.14 (SHD), J2.5, J2.6, J2.7, J2.8, J2.9, J3.1 (GND), J3.17 (GND), J4.6 (GND), S1.1, S1.3, S1.4, U2.19 (TESTEN), U2.57 (GND), U3.4 (GND), U3.9 (EP), X1.2, X1.4; also elsewhere on the board
unnamed: D1.2, R12.1
unnamed: D2.2, R13.1
unnamed: R14.1, S1.2
unnamed: R15.2, U2.36 (GPIO24)
unnamed: R3.1, U2.26 (RUN)
unnamed: C12.2, U2.20 (XIN), X1.1
unnamed: C13.2, U2.21 (XOUT), X1.3

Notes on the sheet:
SLOT MICRO SD
MEMORY
BOOT SELECT
RP2040
SLOT DS
STATE LEDS
DEV PORT
USB

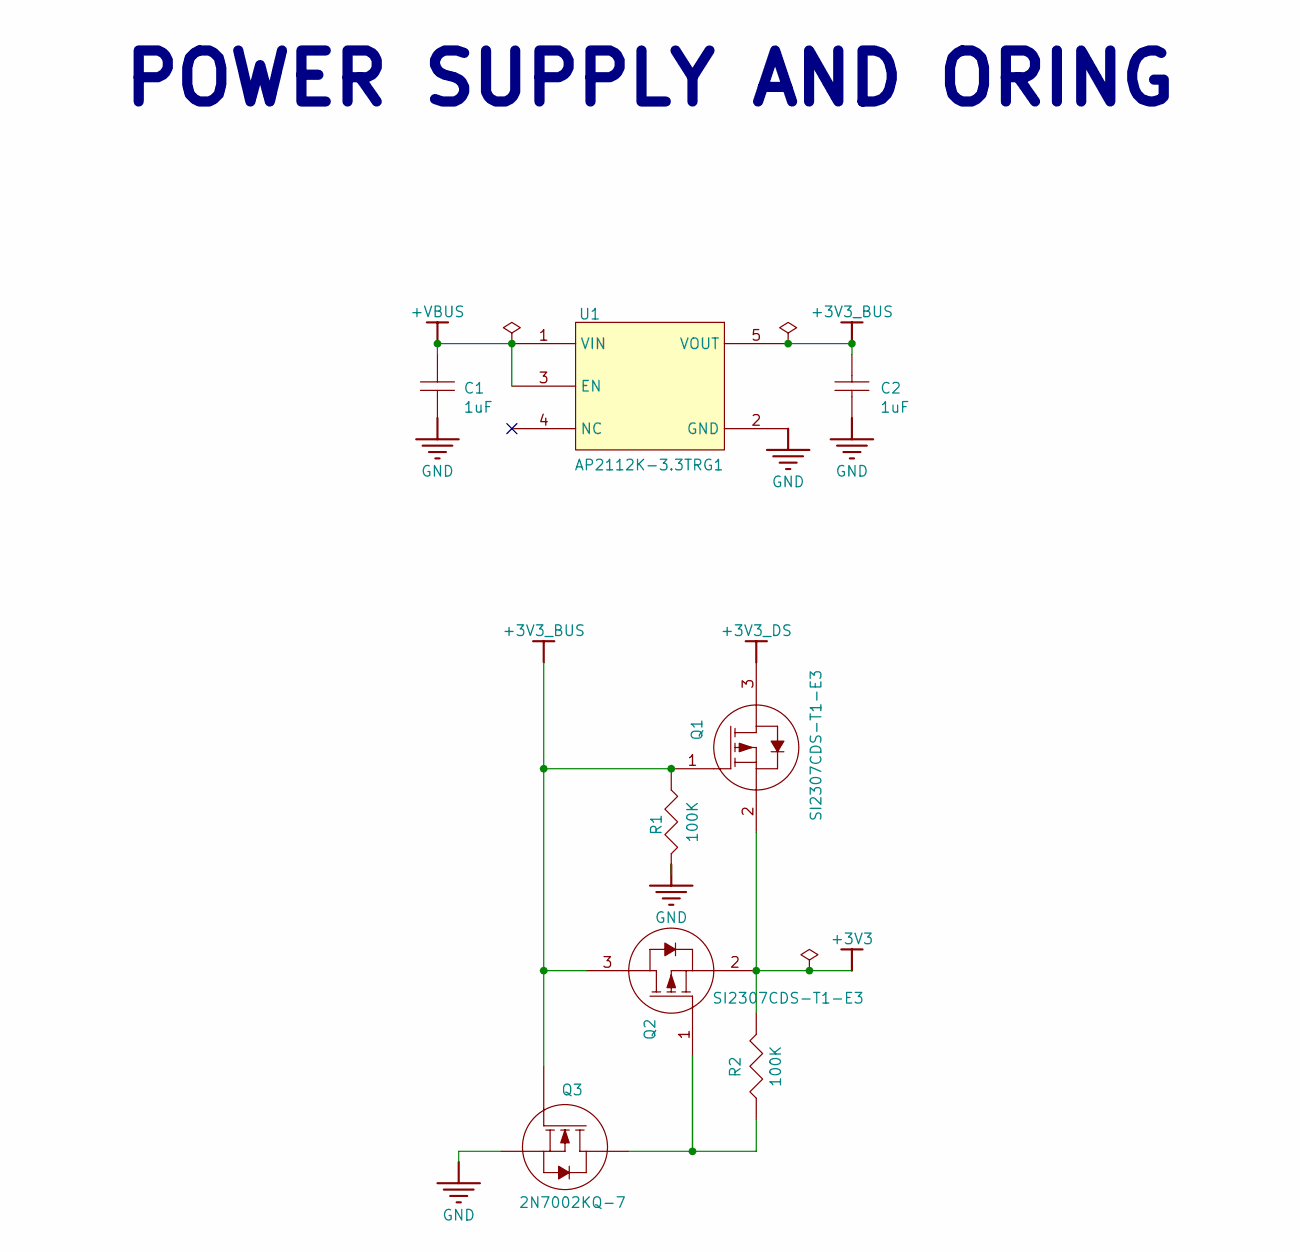
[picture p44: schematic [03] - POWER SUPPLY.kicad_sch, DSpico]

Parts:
C1, C2: 1uF; C0402; TOLERANCE 10%; VOLTAGE RATING 25V; MANUFACTURER PART NUMBER C1005X5R1E105K050BC
Q1, Q2: SI2307CDS-T1-E3; SOT-23_L2.9-W1.3-P1.90-LS2.4-BR
Q3: 2N7002KQ-7; SOT-23_L2.9-W1.3-P1.90-LS2.4-BR; MANUFACTURER PART NUMBER 2N7002KQ-7
R1, R2: 100K; R0402; TOLERANCE 1%; POWER RATING 63mW; MANUFACTURER PART NUMBER CRCW0402100KFKED
U1: AP2112K-3.3TRG1; SOT95P285X140-5N; DROPOUT VOLTAGE 250mV; OUTPUT VOLTAGE 3.3V; MANUFACTURER PART NUMBER AP2112K-3.3TRG1

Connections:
+3V3: Q1.2 (S), Q2.2 (S), R2.2; also elsewhere on the board
+3V3_BUS: C2.2, Q1.1 (G), Q2.3 (D), Q3.1 (G), R1.1, U1.5 (VOUT); also elsewhere on the board
+3V3_DS: Q1.3 (D); also elsewhere on the board
+VBUS: C1.2, U1.1 (VIN), U1.3 (EN); also elsewhere on the board
GND: C1.1, C2.1, Q3.2 (S), R1.2, U1.2 (GND); also elsewhere on the board
unnamed: Q2.1 (G), Q3.3 (D), R2.1

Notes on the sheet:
POWER SUPPLY AND ORING

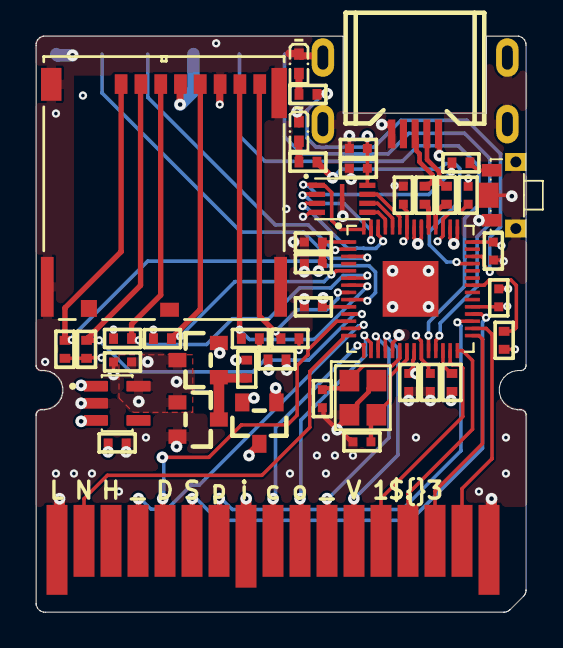
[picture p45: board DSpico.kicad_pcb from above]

Board: 4 copper layers, 27.2 x 32.0 mm, 44 parts (1 on the bottom side), 49 nets.

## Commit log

2026-01-31 Added extra pegs
    [dspico-shell-bottom_v1-5-FR.stl, dspico-shell-bottom_v1-5.step, dspico-shell-bottom_v1-5.stl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]
2026-04-10 Add KiCad design files for DSpico v1.3
    [DSpico.kicad_pcb, DSpico.kicad_sch, [01] - COVER PAGE.kicad_sch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]
